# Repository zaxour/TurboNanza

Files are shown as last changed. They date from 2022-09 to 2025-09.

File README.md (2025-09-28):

# TurboNanza
[PC Engine Shuttle Installation Instructions](/images/shuttle/readme.md)

[PC Engine/Turbo Duo Installation Instructions](/images/duo/readme.md)

An internal RGB, S-Video, Composite video and Audio modification for the Turbografx 16, PCEngine and CoreGrafx. As of Revision C, support has been added for audio from the Turbo Everdrive Pro.

Design is KiCad format and all files necessary to open the design and have it fabricated are present within the archive.

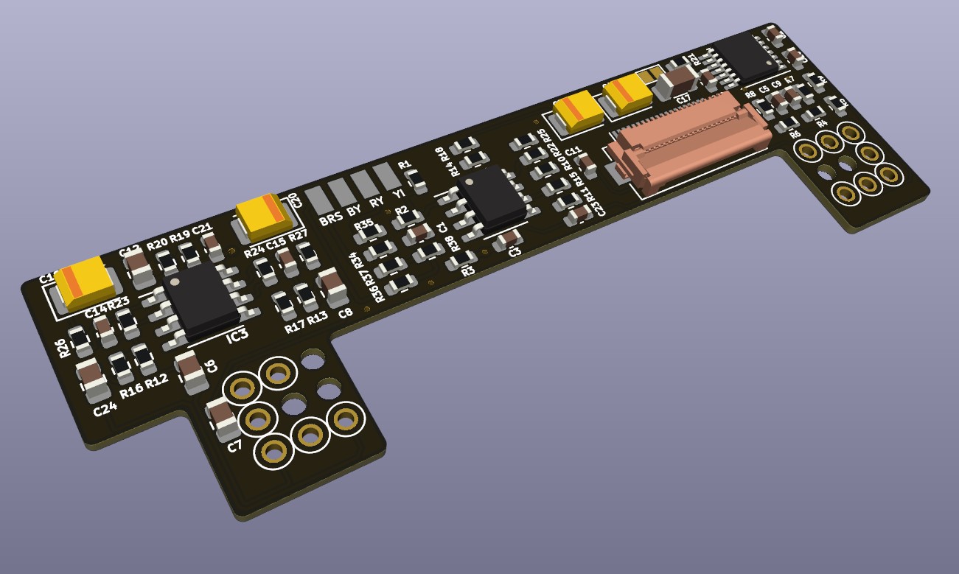
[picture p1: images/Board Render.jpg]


Installation Method (WORK IN PROGRESS!!):

PINOUT (For reference/Non-Expansion-Port Installs):
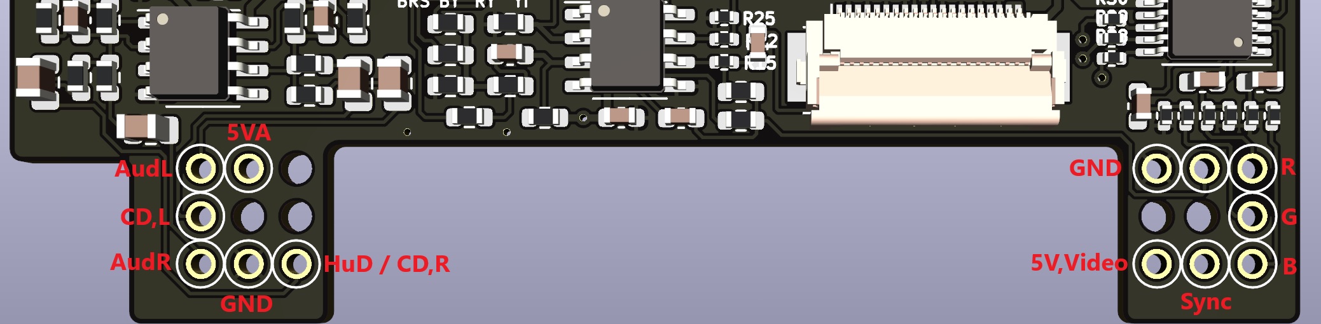
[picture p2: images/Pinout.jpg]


## Step 1 - Remove the resistors for Luma, R-Y, B-Y, and Burst
### PC Engine & CoreGrafx

Remove resistors R134, R137, R138 and R156 

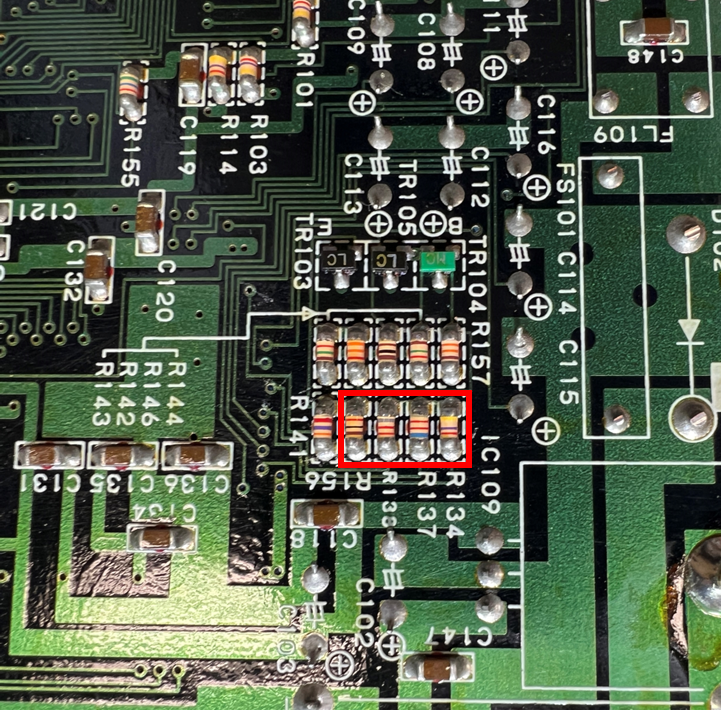
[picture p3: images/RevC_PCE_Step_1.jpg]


### TurboGrafx 16
Remove resistors R130-R132 and R134
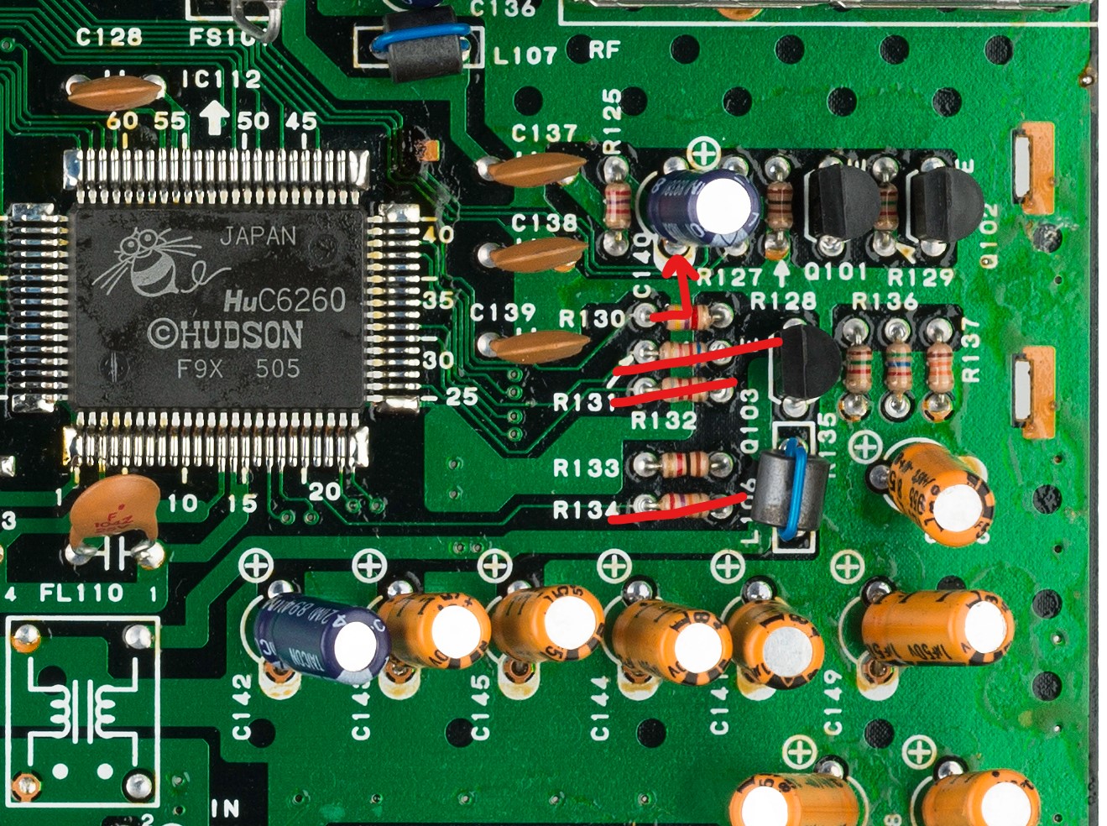
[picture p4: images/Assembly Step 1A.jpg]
Step 1


### SuperGrafx
Remove resistors R164-167
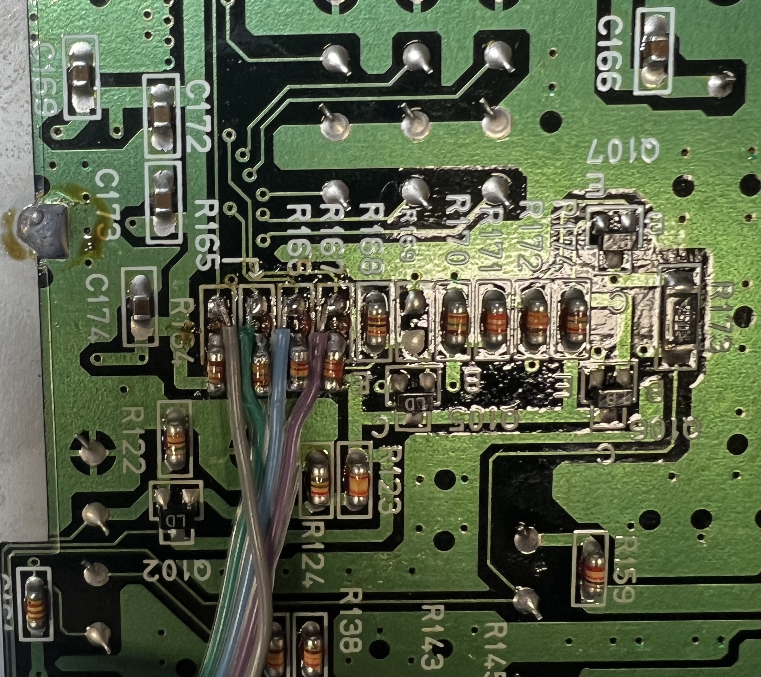
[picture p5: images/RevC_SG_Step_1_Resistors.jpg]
Step 1


## Step 2 - Disconnect CVBS pin from original circuit
### PC Engine & CoreGrafx
Remove resistor R145 (20 ohms)

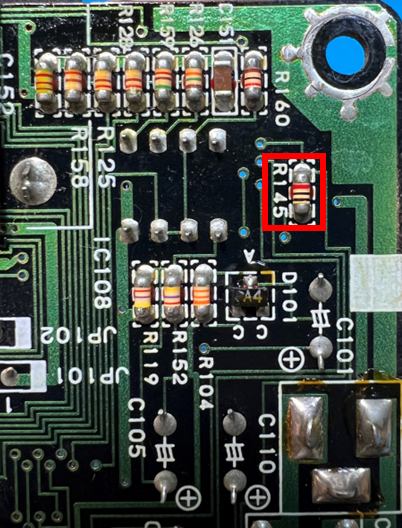
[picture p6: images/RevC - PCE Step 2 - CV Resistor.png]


### TurboGrafx 16
Remove resistor R127 (20 ohms)

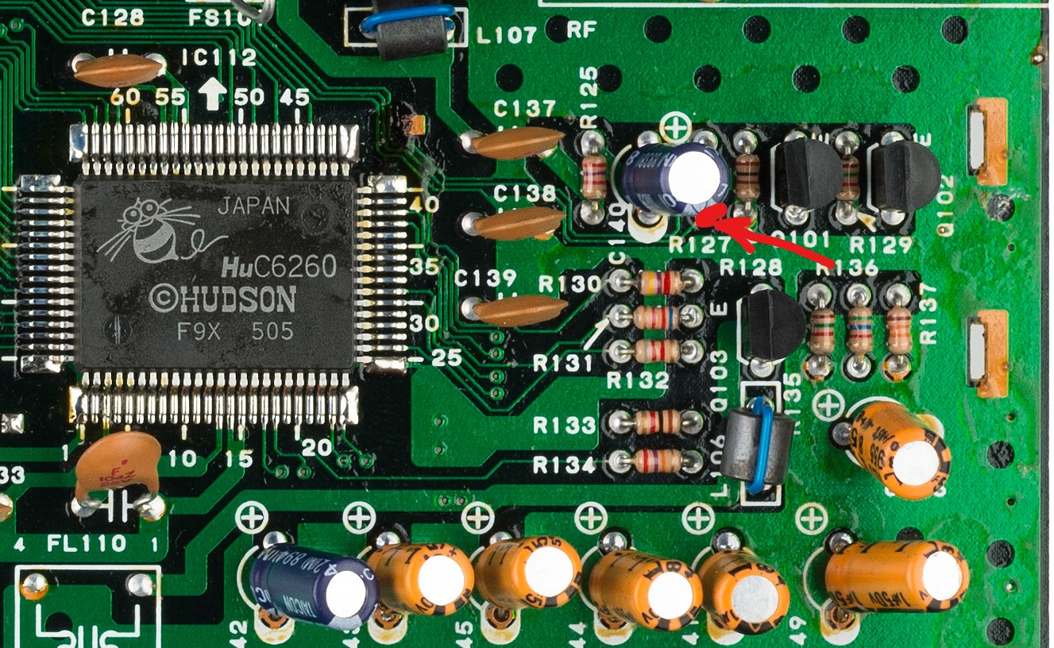
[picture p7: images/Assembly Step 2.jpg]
Step 2


### SuperGrafx
Remove resistor R147 

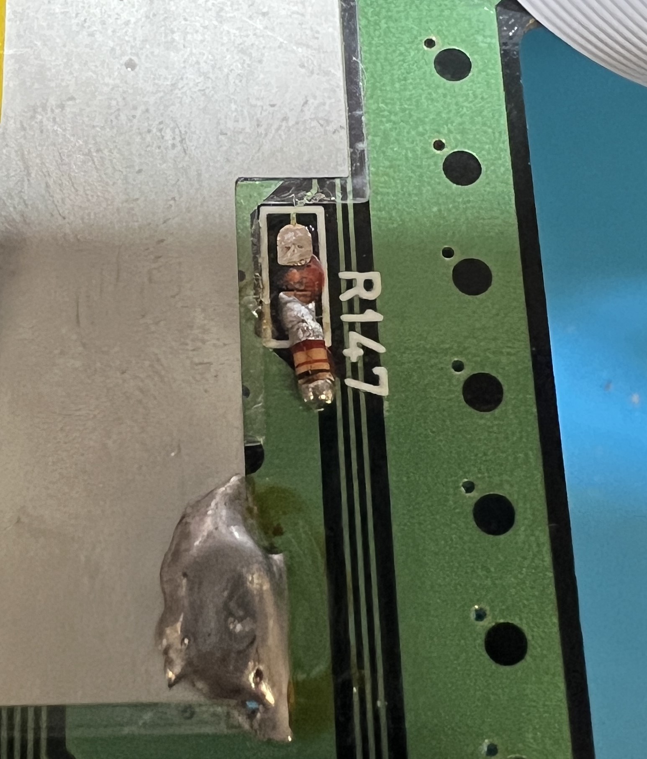
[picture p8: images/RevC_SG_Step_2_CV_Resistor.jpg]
Step 2


## Step 3 - Install TurboNanza
### PC Engine & CoreGrafx
Solder the TurboNanza over the expansion port pins as shown.
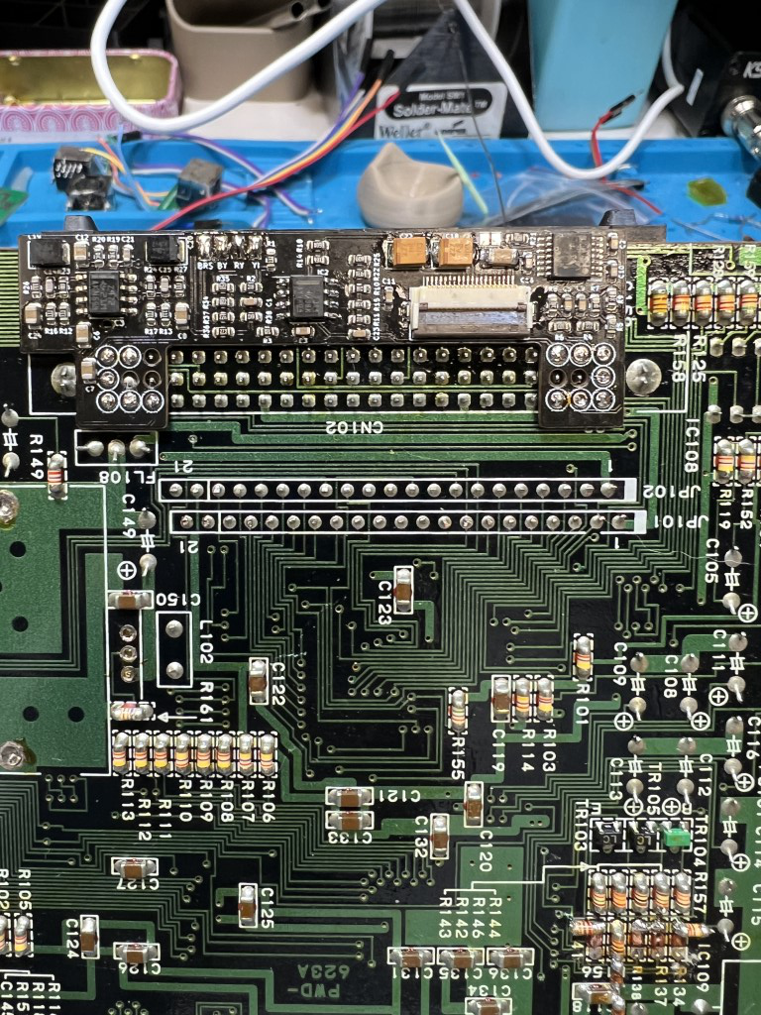
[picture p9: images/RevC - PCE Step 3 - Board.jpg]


### TurboGrafx16
Solder the TurboNanza over the expansion port pins as shown.
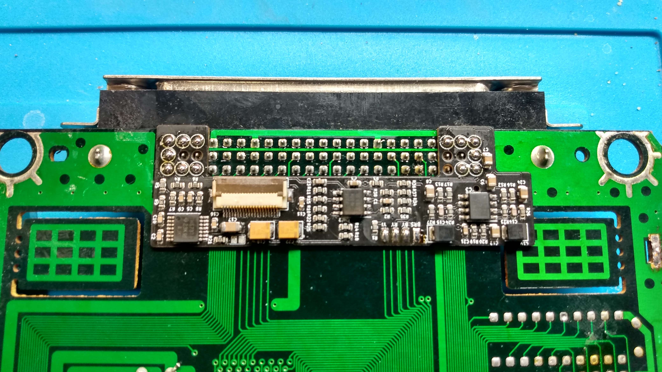
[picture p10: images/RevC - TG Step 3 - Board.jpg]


### SuperGrafx
Prepare the flex cable by tinning the pads as shown.

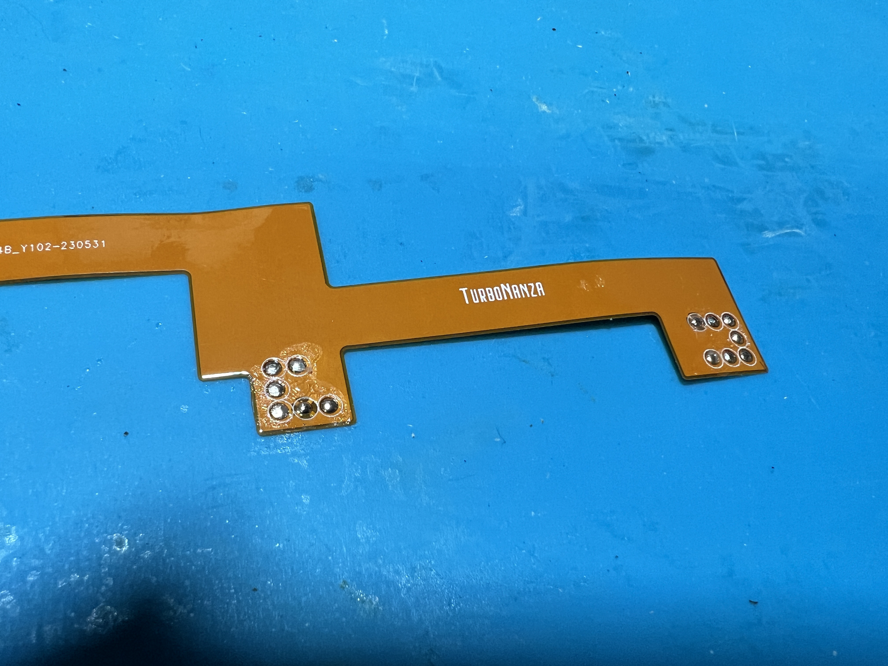
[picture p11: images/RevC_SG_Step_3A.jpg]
Step 3A


Solder the TurboNanza to the flex cable as shown. It's recommended to verify continuity. Place some kapton/polyimide tape over the exposed solder pads on the bottom of the flex cable to avoid shorting to the shielding.
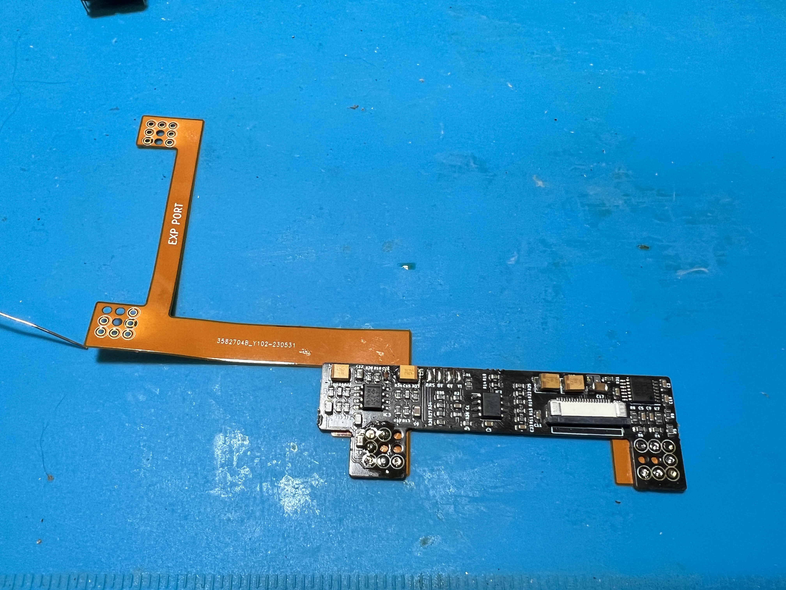
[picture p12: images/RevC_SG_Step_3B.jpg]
Step 3B


Solder the TurboNanza/Flex Cable combo over the expansion port pins as shown (ignore 4 wires at this time).
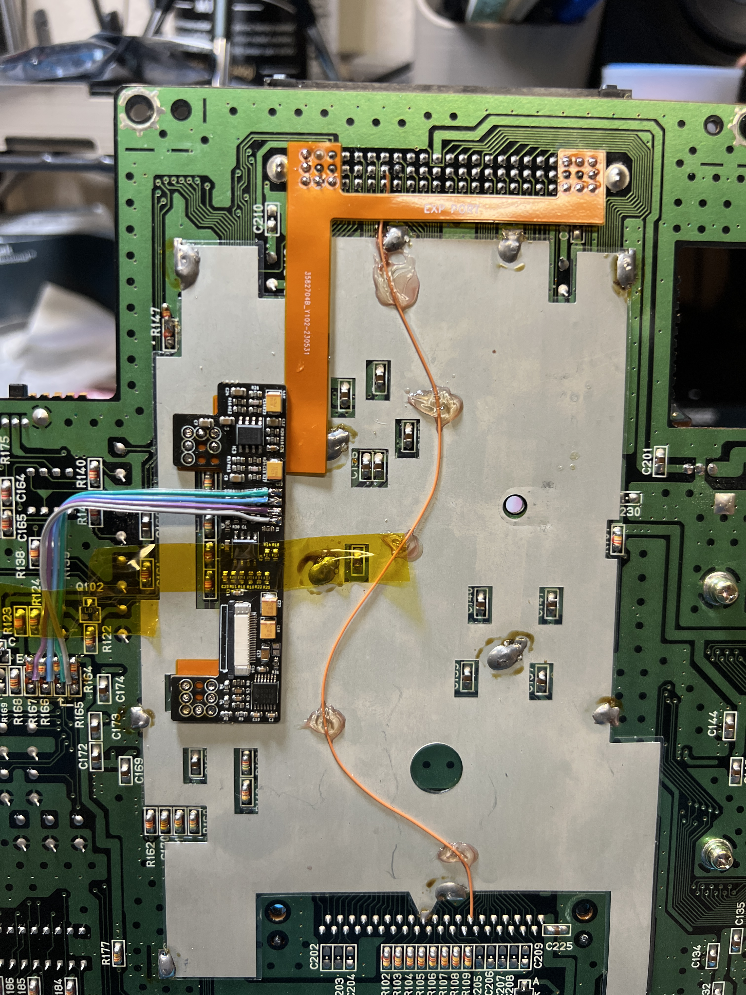
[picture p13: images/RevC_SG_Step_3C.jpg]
Step 3C


## Step 4 - Solder S-Video connections

**When soldering the Y/B-Y/R-Y/Burst wires, try to use as close to the exact same length of wire as possible to maintain proper phase shift!**

### PC Engine & CoreGrafx
Solder wires from the points shown to the pads on TurboNanza
(Do not remove R141, as previously directed. The Color Burst trace runs underneath and can easily sever. Leave R141 on and solder directly to the resistor pad)

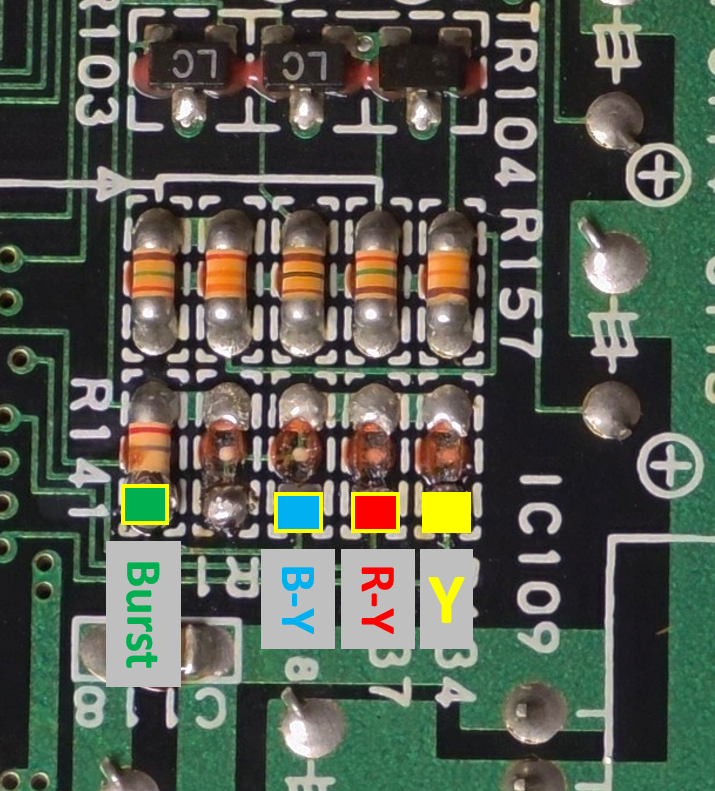
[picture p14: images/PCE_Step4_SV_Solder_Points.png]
Step 4


### TurboGrafx 16
Solder wires from the points shown to the pads on TurboNanza
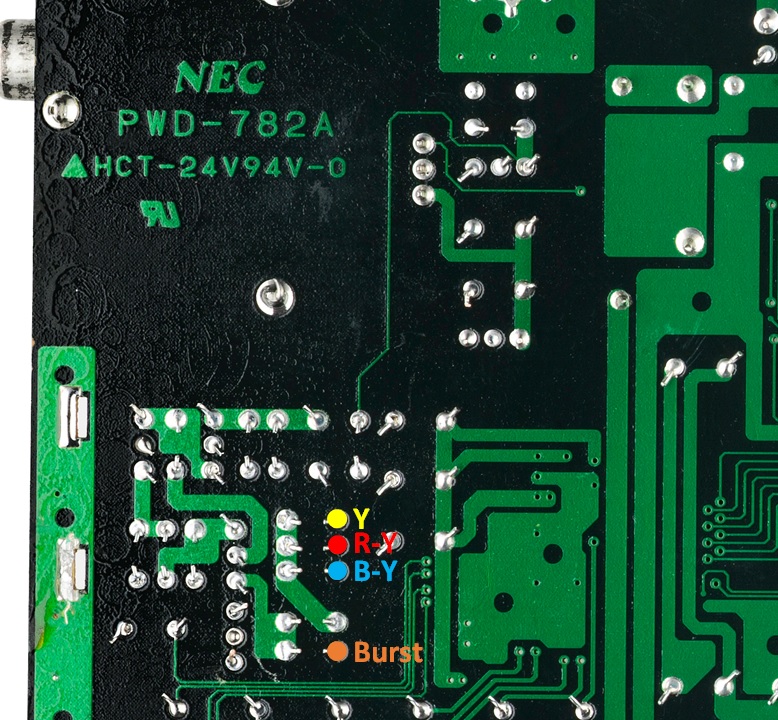
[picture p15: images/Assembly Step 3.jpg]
Step 4 Step 3


### SuperGrafx
Solder wires from the points shown to the pads on TurboNanza
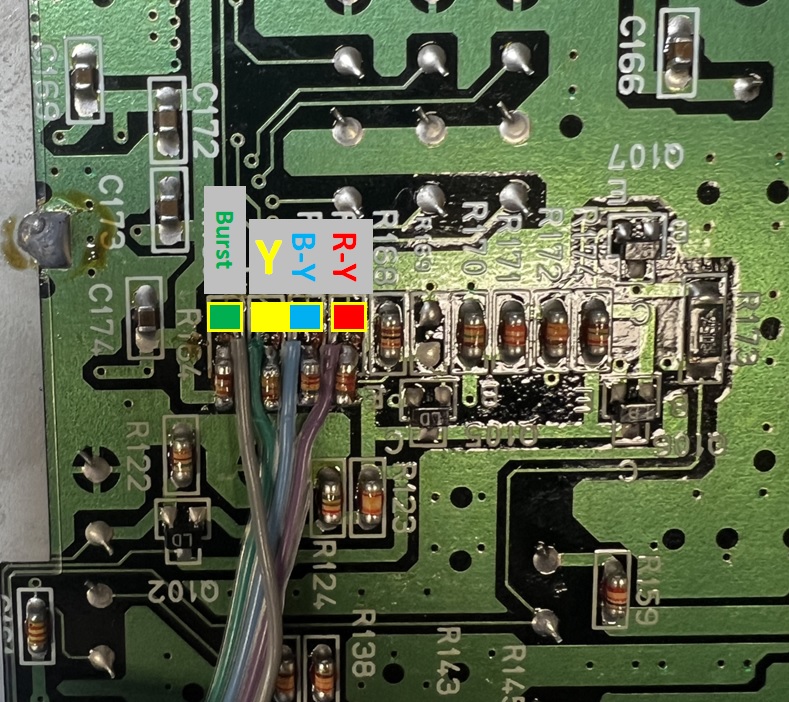
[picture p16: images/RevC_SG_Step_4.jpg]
Step 4


## Step 5 - Attach the DIN to the main board
### PC Engine
Kits sold after 8/15/2023 now include a mounting board for the PCEngine. It is recommended to secure with two size M2 or 2-56 bolts/washers to allow for easy positioning.

Position the mount and loosely secure with screws/washers. The board may also be soldered - kapton/polyimide tape is recommended to position the board.
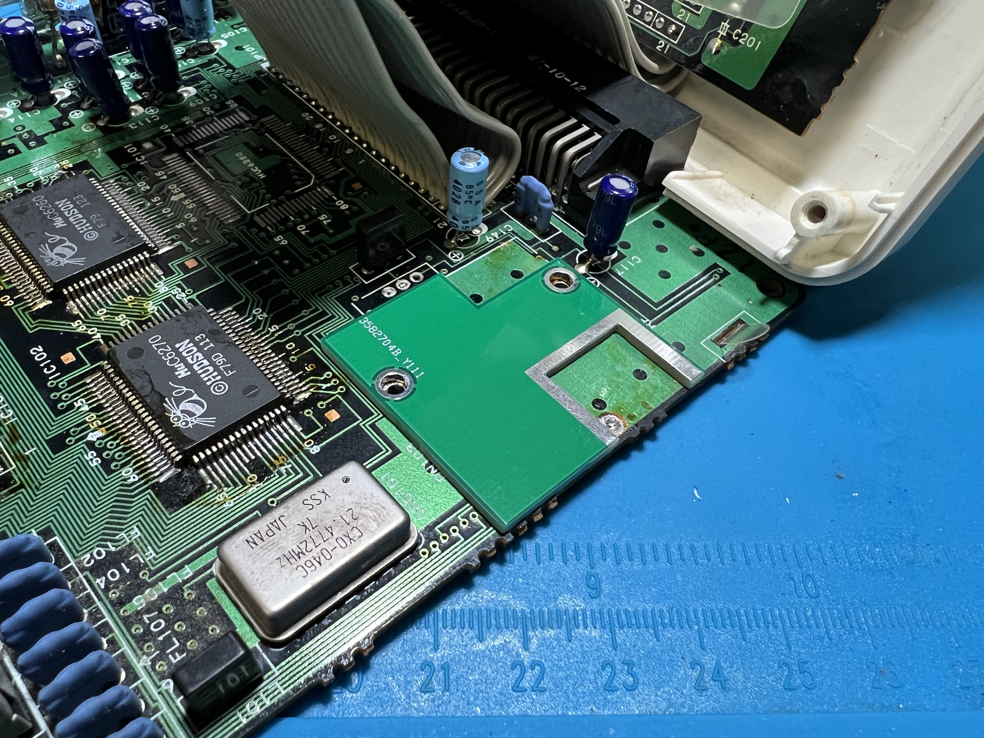
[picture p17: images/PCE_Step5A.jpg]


Place the DIN in the slot, and solder around the sides.
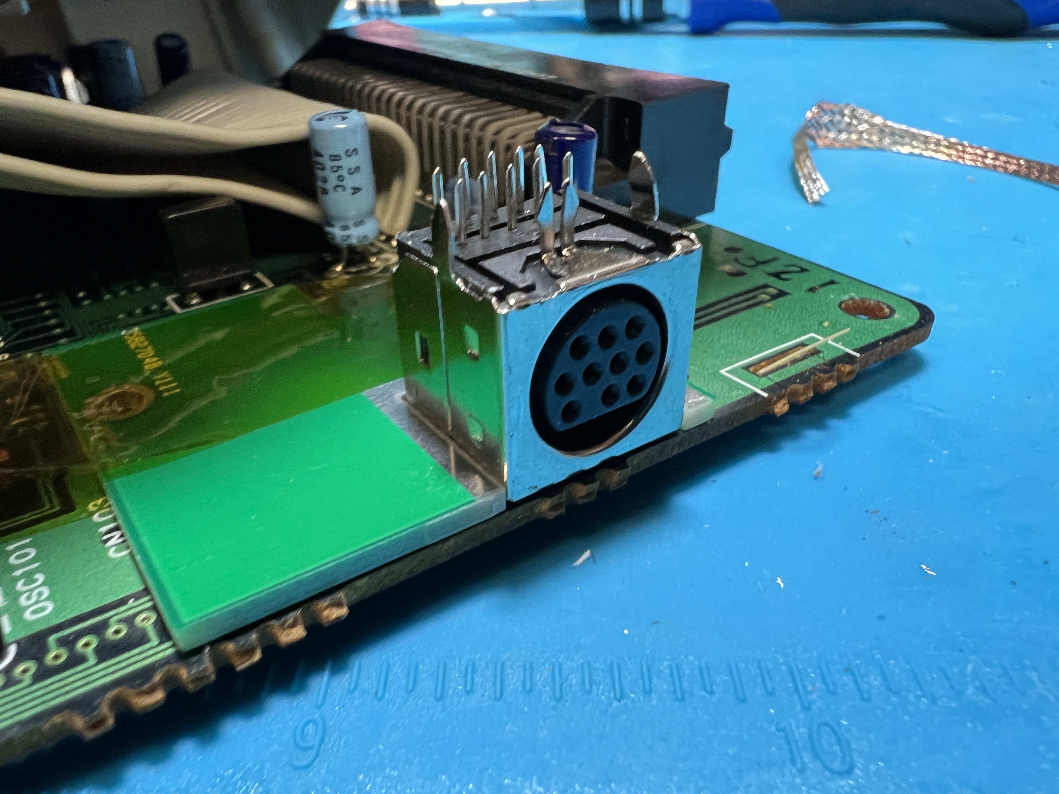
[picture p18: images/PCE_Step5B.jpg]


Solder the DIN FFC adapter to the DIN. Please make sure the "THIS SIDE TOP" text is visible before soldering, as it indicates which side is top.
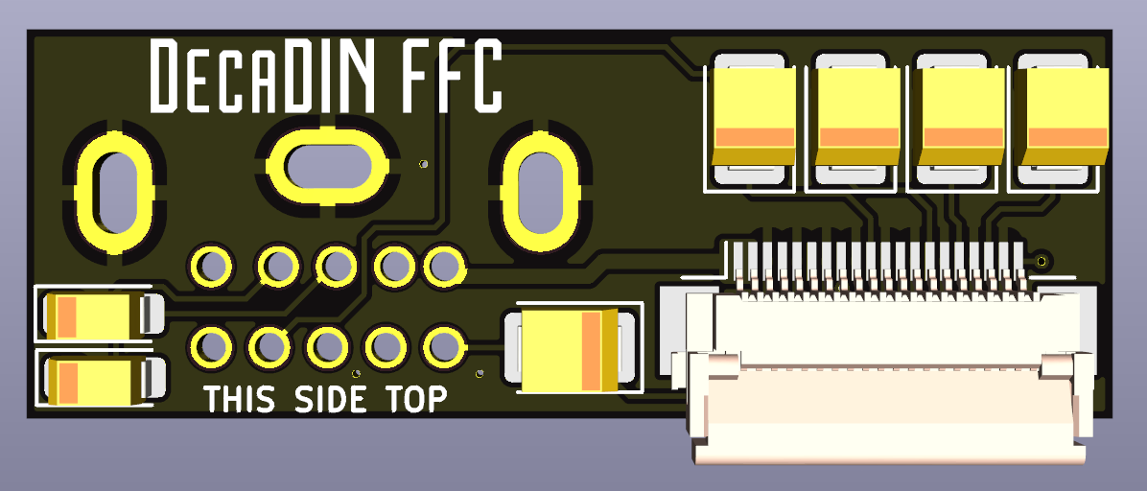
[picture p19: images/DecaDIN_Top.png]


### CoreGrafx
First, remove C162 (AC coupling capacitor for composite video - no longer necessary)
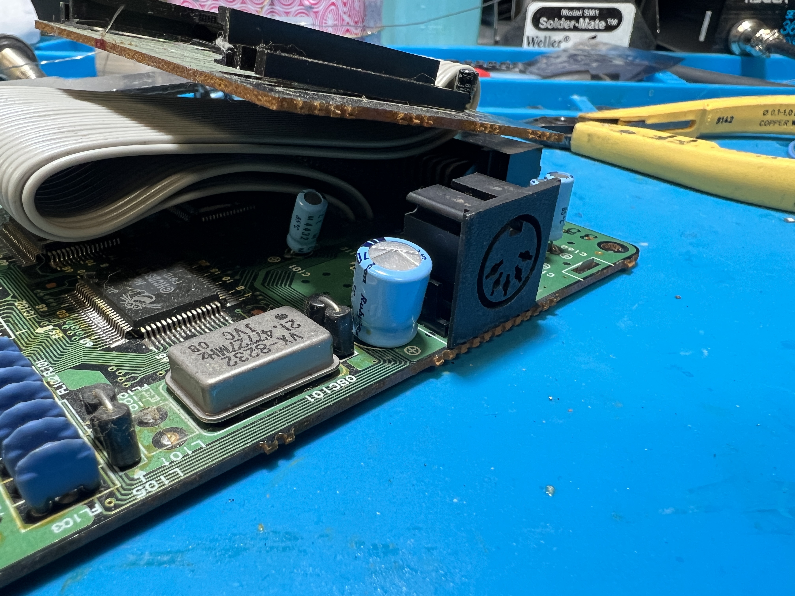
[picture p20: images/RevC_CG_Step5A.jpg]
Step 5


Scrape the solder mask off the copper on the left and right edges of the original DIN footprint as shown.
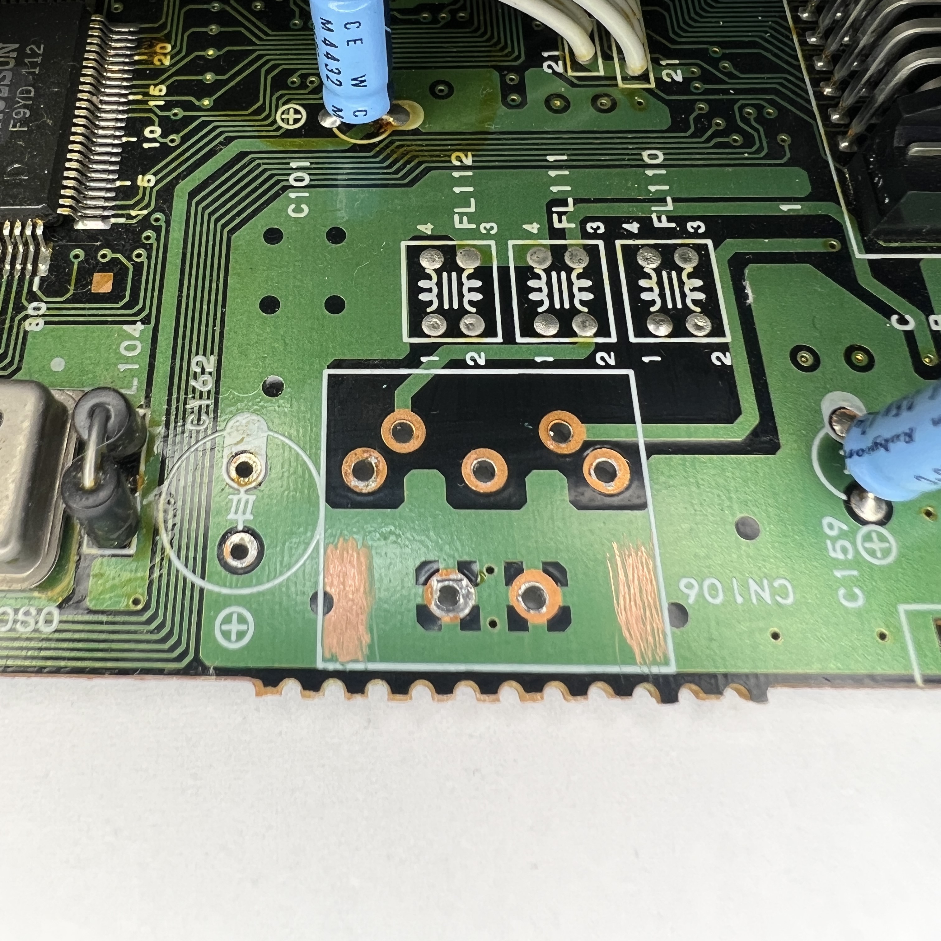
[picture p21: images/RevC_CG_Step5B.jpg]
Step 5


Solder the supplied mounting board to the mainboard.
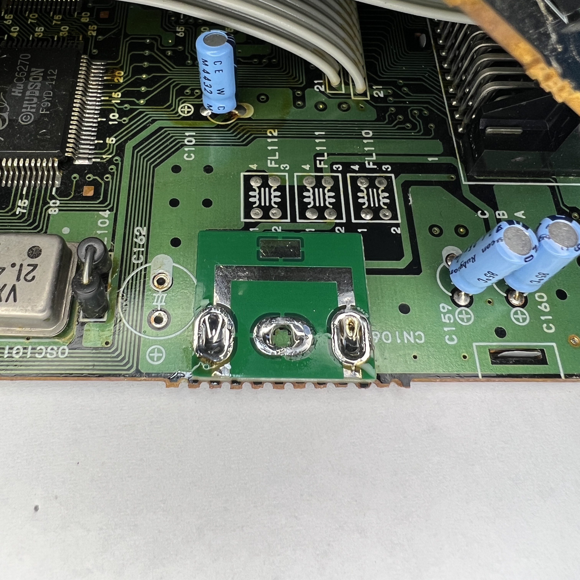
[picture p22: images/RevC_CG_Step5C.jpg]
Step 5


Solder the DIN FFC adapter to the DIN. Please make sure the "THIS SIDE TOP" text is visible before soldering, as it indicates which side is top.


### TurboGrafx16
Solder the mounting board using the plated through holes for the RF modulator. Align the DIN on the mounting board such that it aligns with the console shell opening and solder in place.

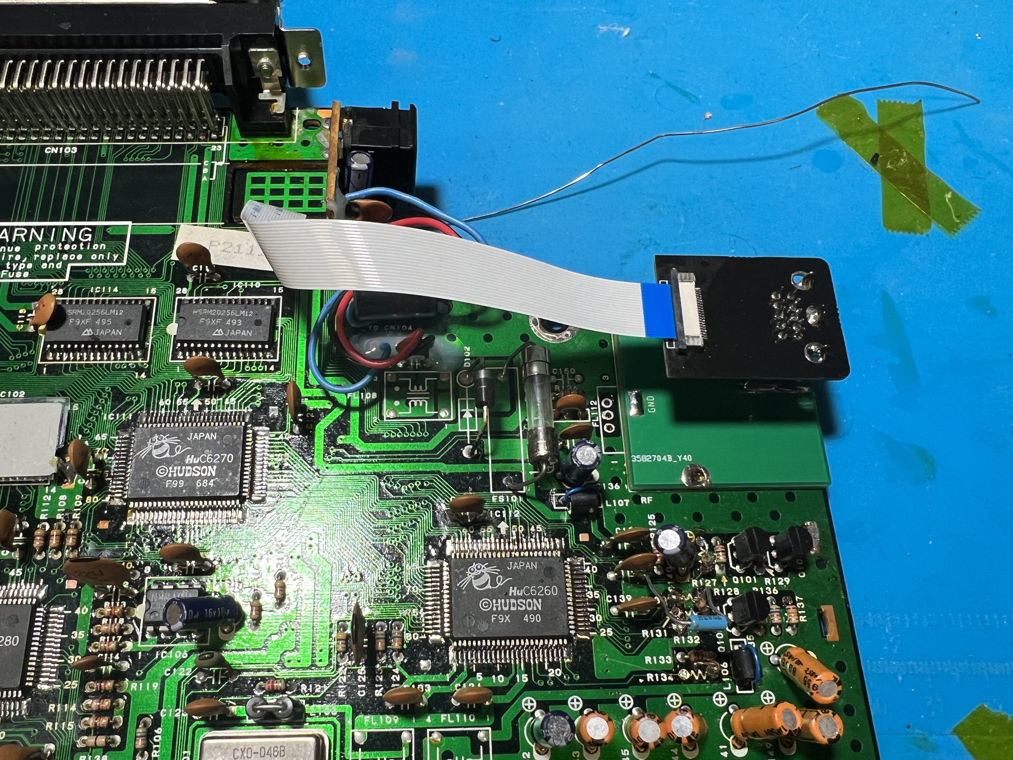
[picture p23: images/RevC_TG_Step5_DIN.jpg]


### SuperGrafx
Remove the original DIN and scrape the soldermask approximately as shown.
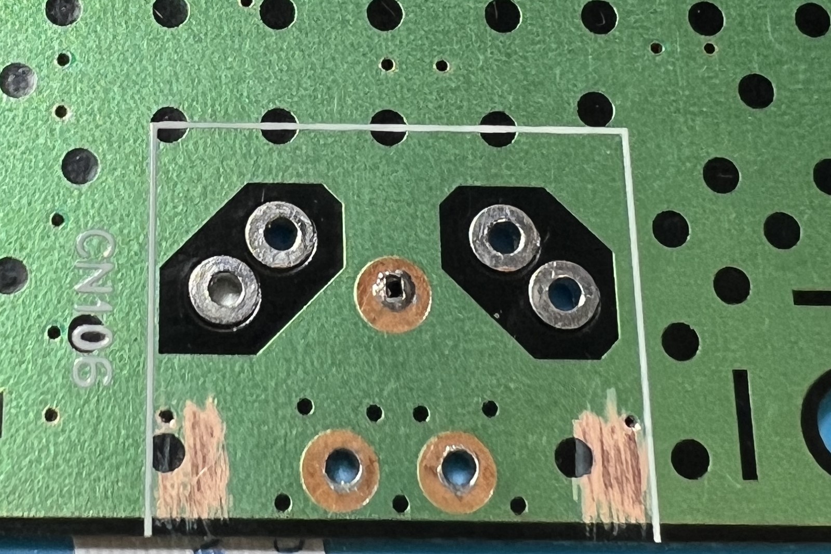
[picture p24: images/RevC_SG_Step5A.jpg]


Solder the mounting board as shown, aligning the center hole with the two ground through holes.
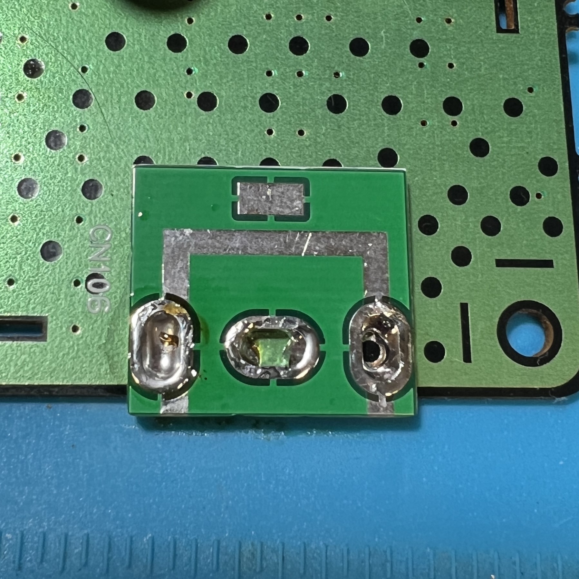
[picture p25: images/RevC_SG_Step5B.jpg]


Mount the DIN and DIN board to the mount board.
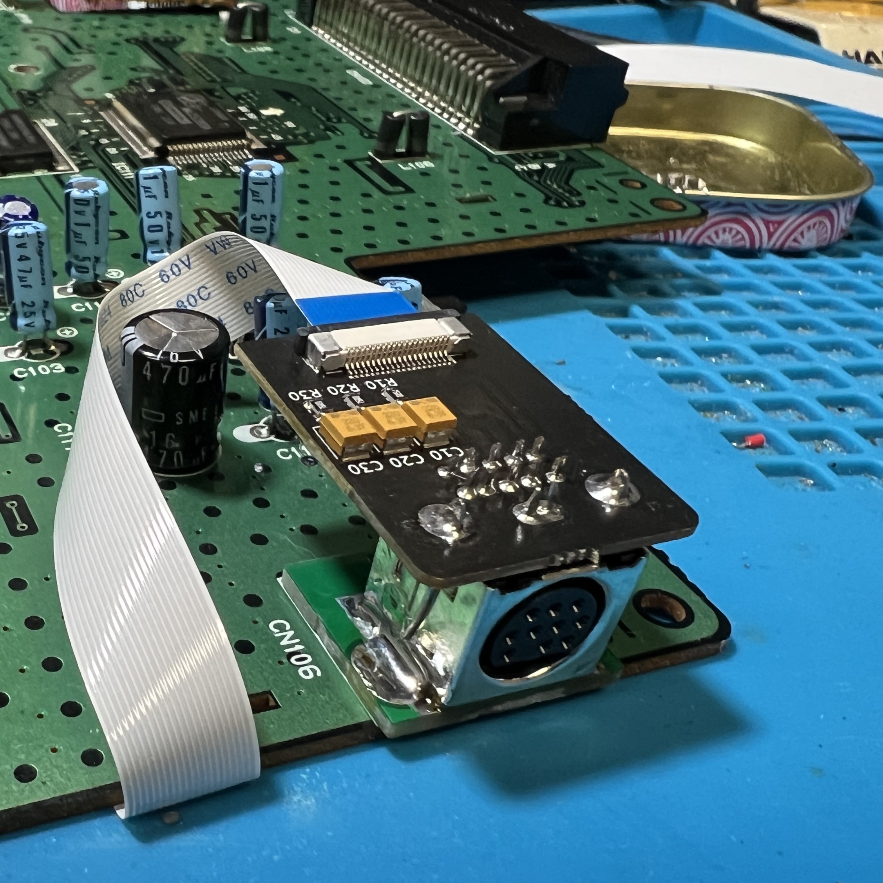
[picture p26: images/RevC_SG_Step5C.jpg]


## Step 6 - RF Shielding and Case trimming
### PC Engine
On the bottom shell of the case, trim the 2 ribs where the expansion port opening sits. Do not re-install the original shielding. If your PC Engine has shielding that has two tabs that solder close to the EXP port pins, you will need to run a wire to where the shielding originally terminated.
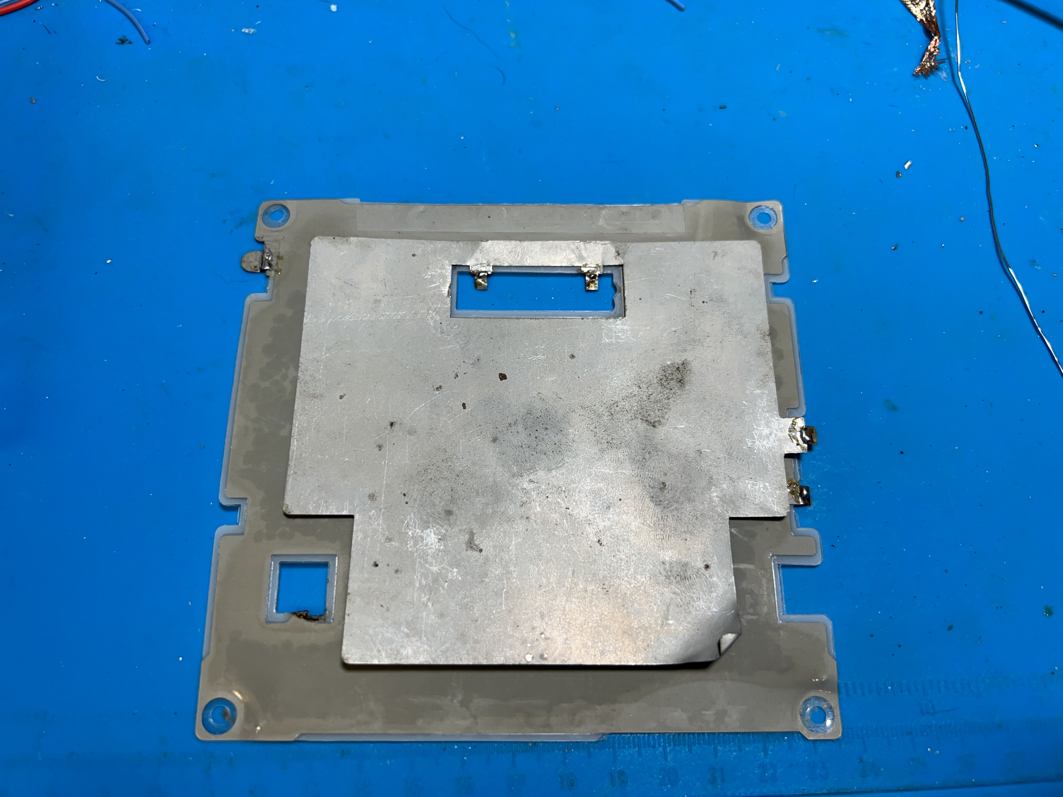
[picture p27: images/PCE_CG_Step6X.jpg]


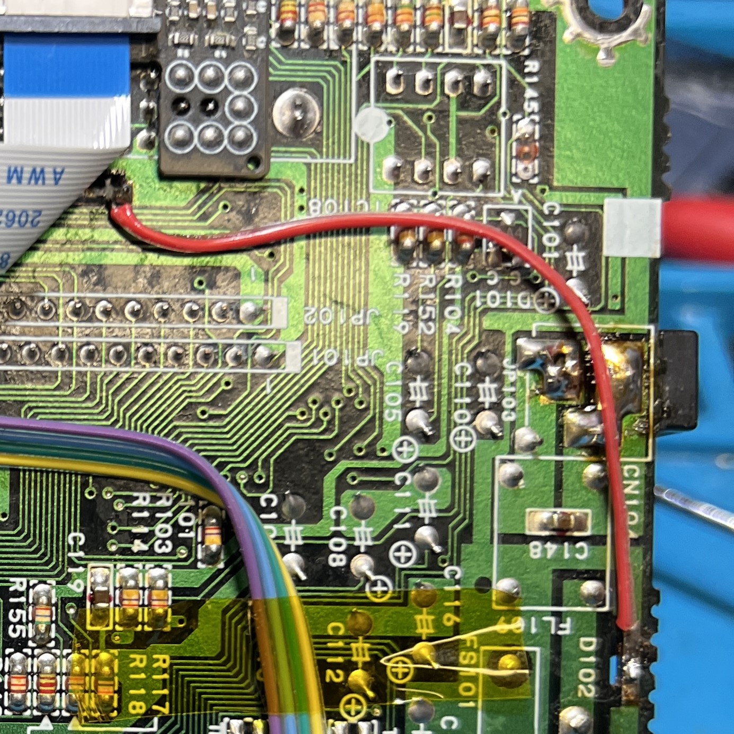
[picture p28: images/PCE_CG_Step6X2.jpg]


### CoreGrafx
Trim the RF shield such that the metal lip is not contacting the TurboNanza.

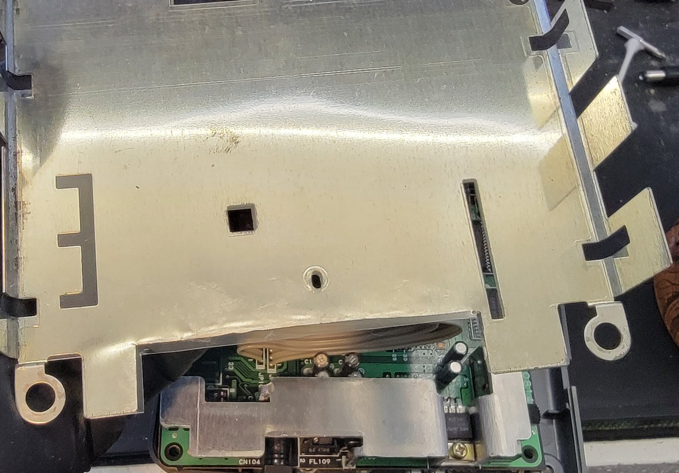
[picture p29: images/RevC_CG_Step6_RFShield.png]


Like the PC Engine, trim the 2 ribs on the bottom shell where the expansion port opening is.

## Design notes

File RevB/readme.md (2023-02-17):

# TurboNanza - Revision A/B
An internal RGB, S-Video, Composite video and Audio modification for the Turbografx 16.

Design is KiCad format and all files necessary to open the design and have it fabricated are present within the archive.



For RGB and Audio portions, simply fit the PCB over the expansion pins and solder down, then connect the output pins for RGB, Sync and Audio Left/Right to the corresponding pins of your chosen output connector.

To add S-video, First pull the left leg of R130 out of circuit as shown in the picture below, and connect the resistor to ground. Then remove resistors R131, R132 and  R134). Leave the Plated Through Holes open. Grounding R130 grounds the base for the composite mixing NPN transistor through R133.
Step 1

Next, pull the bottom leg of R127 out of circuit.
Step 2

Finally, solder your wires for Y (Luma), R-Y, B-Y, and Color Burst to the points on the bottom of the board as shown. Connect these wires to the "YI", "RY", "BY" and "BRS" pads on the TurboNanza, and solder bridge the jumper for "CV", which will send the remixed composite video to the "V" output pad on the TurboNanza.
Step 3
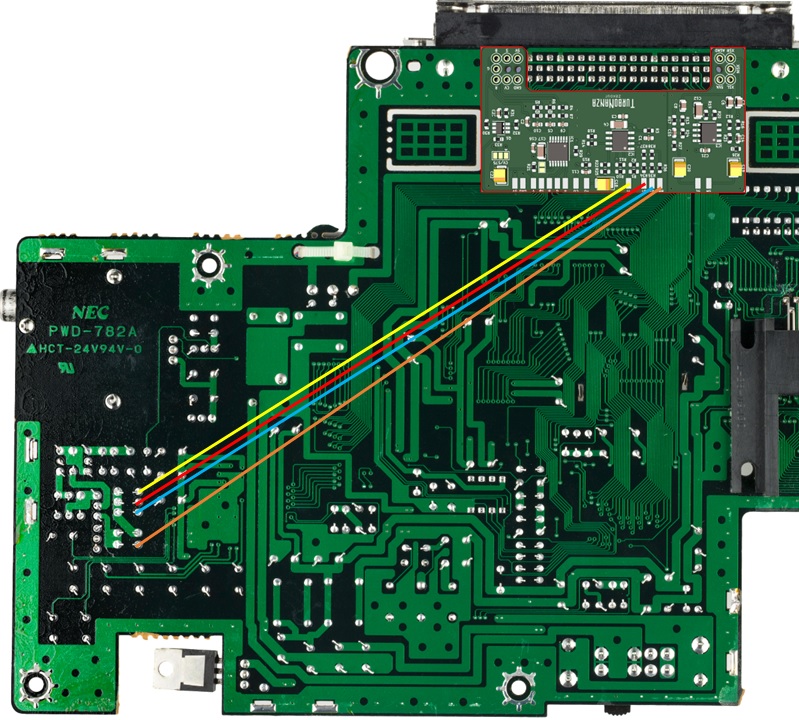
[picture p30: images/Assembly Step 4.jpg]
Step 4


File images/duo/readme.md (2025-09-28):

# Turbonanza - Duo Installation Instructions

This document covers the installation process for a PC Engine/Turbo Duo (original model). Thanks to [PowrUpGaming](https://twitter.com/PowrUpGaming) for the install photos.

The same general idea can be applied to the Duo R/RX installation, with the difference being that the HuC6260 is on the top side instead of bottom.

## Step 1 - Determine Mounting Location
Find a mounting location for the turbonanza board and secure with double-sided tape or simply with kapton tape. If using double-sided tape, wait until all of the wires are soldered before taping down.
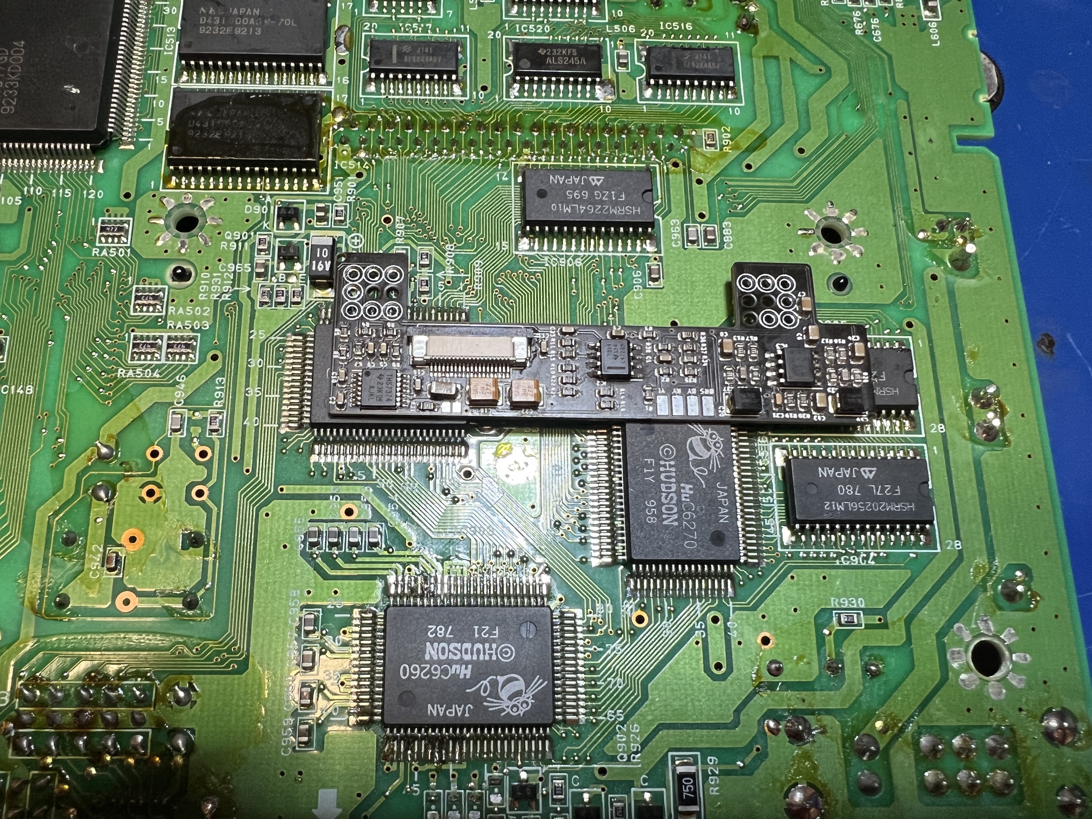
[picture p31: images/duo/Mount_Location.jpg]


## Step 2 - Solder RGB/CSYNC
Solder wires for RGB and SYNC to the HuC6260 pins as shown. The pinout is as follows:

Pin 49 - Red
Pin 47 - Green
Pin 51 - Blue
Pin 44 - Sync

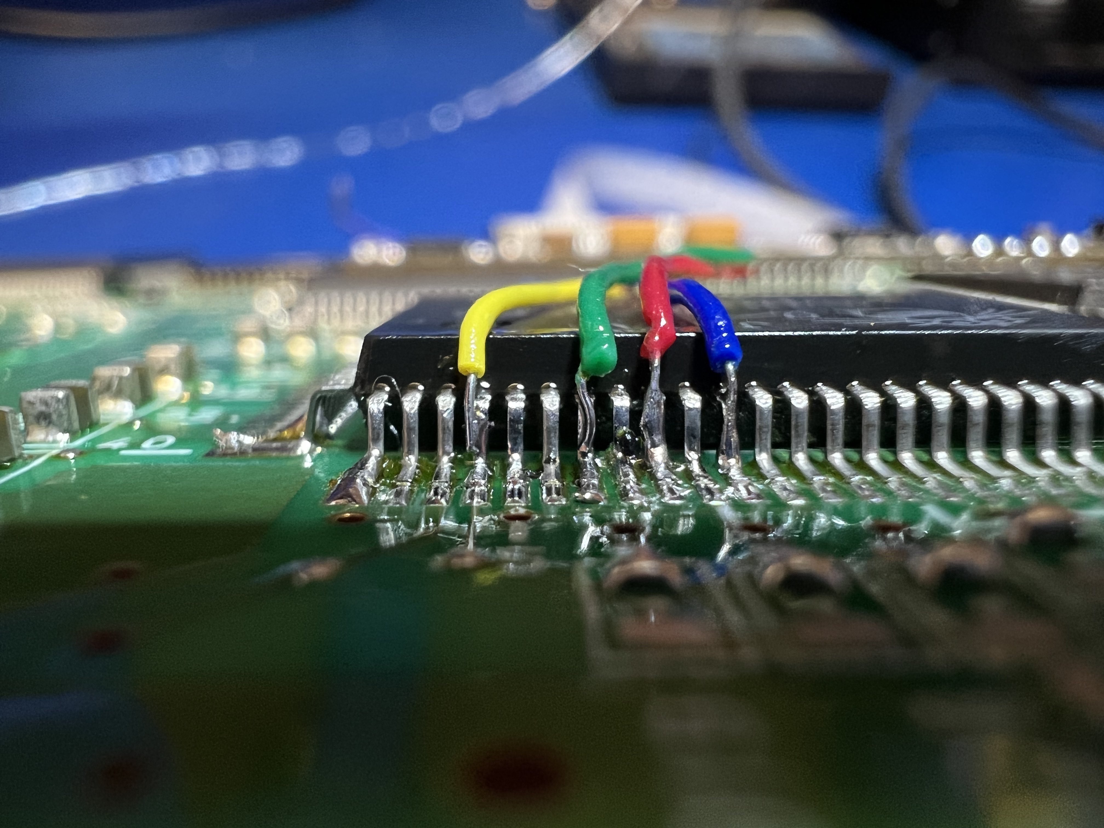
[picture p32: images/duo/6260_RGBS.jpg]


## Step 3 - Remove resistors for S-Video

Remove resistors R919-R922 and solder the 4 wires for Luma (Y), B-Y, R-Y and Burst to the pads indicated.

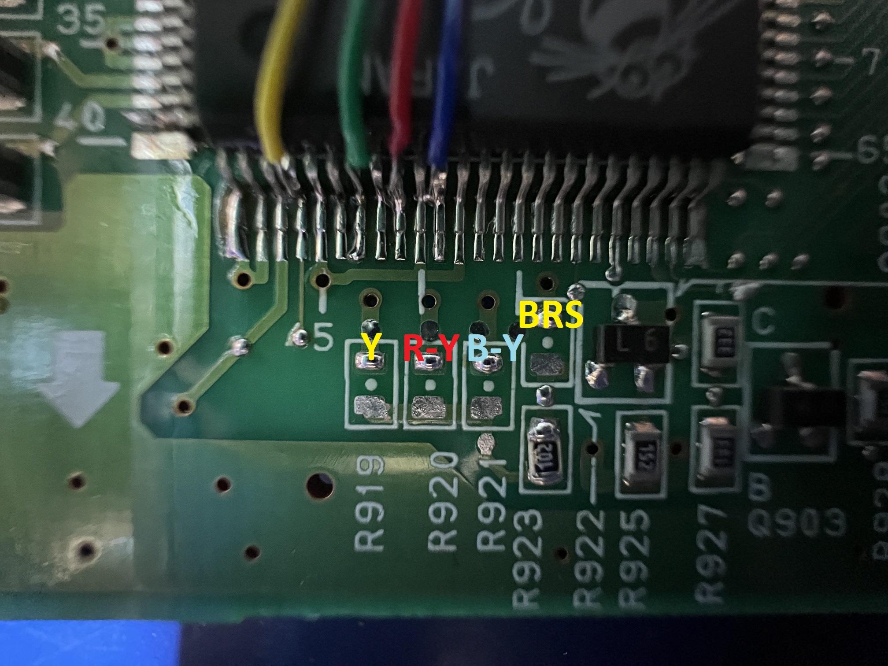
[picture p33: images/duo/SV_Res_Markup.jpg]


## Step 4 - Solder wires for 5V and GND

Locate connections for 5V and GND, preferrably across a capacitor. The following is an example - there are multiple points for 5V/GND available.

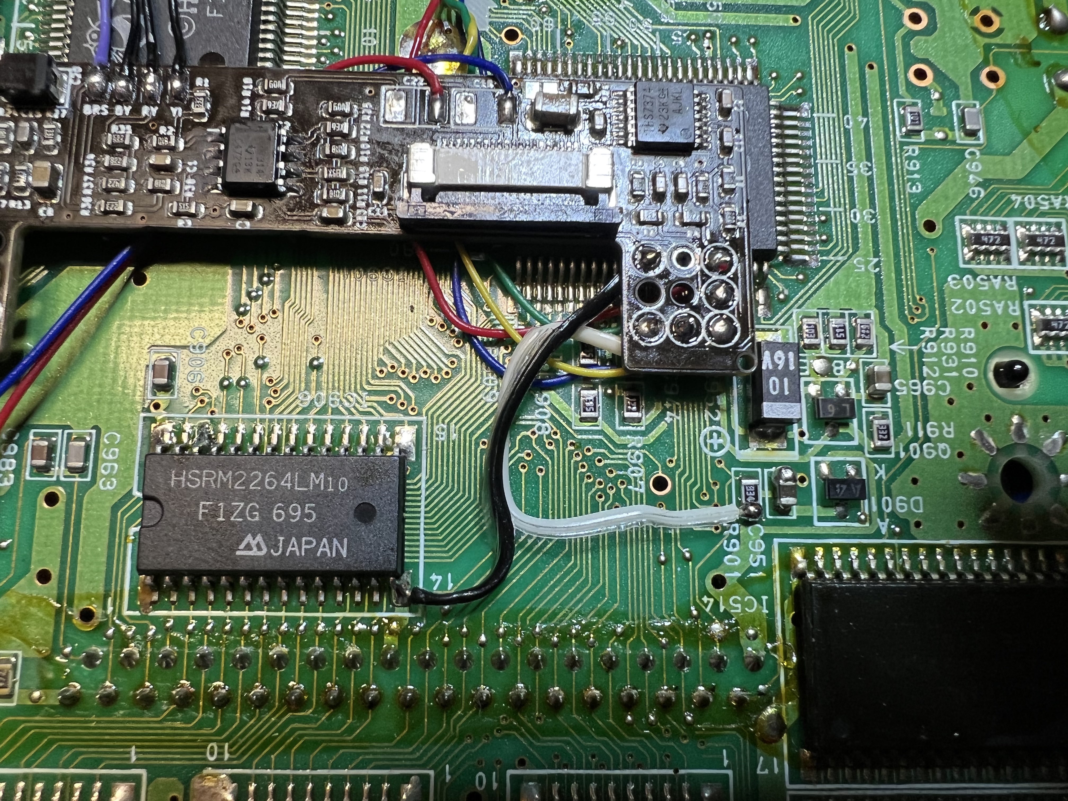
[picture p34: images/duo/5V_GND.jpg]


## Step 5 - Solder all wires to to the Turbonanza

All connections are labeled on the bottom of the board, but this image may also be used as reference.

At this time, the following connections should be made to the turbonanza:
5V, GND, R, G, B, Sync, Y, R-Y, B-Y, Burst

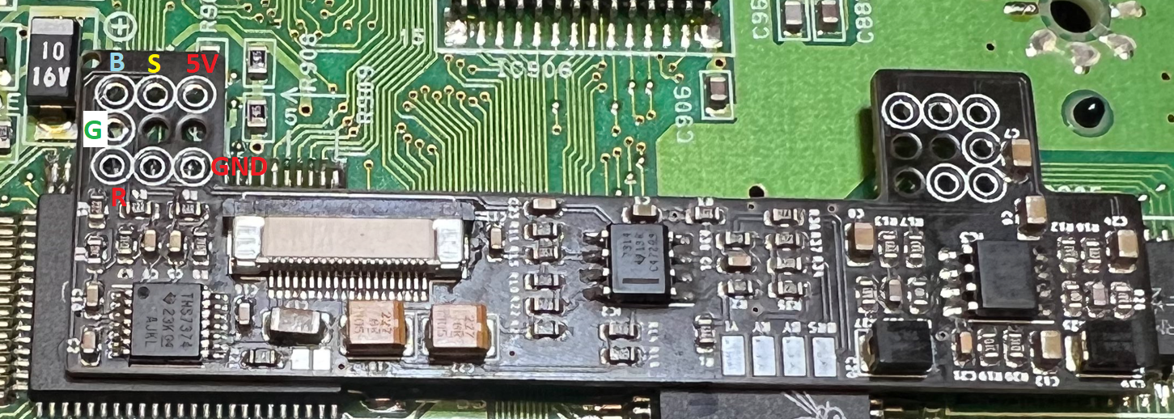
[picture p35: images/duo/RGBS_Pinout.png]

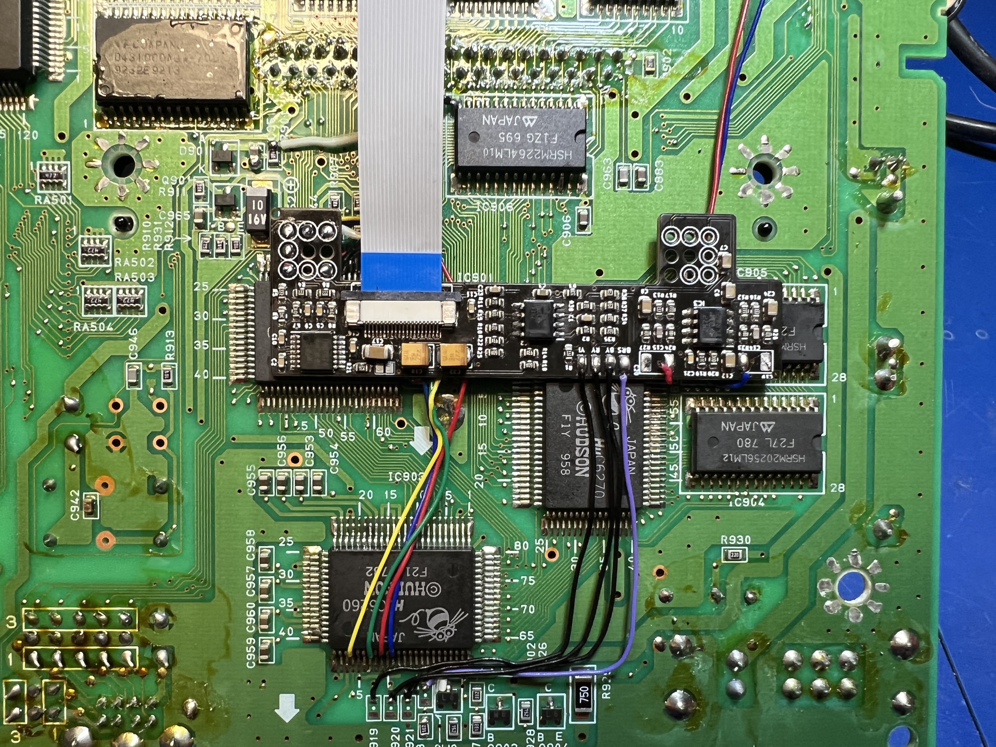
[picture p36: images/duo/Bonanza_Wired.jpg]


## Step 6 - Remove original 5 Pin DIN, install 10 Pin DIN

See CoreGrafx for DIN and mounting board installation.

## Step 7 - Audio

Tap the Duo's audio output circuit - the signals can be directly obtained from the original DIN pins as shown below. 

The blue wire is Left audio, while the red wire is for Right audio.

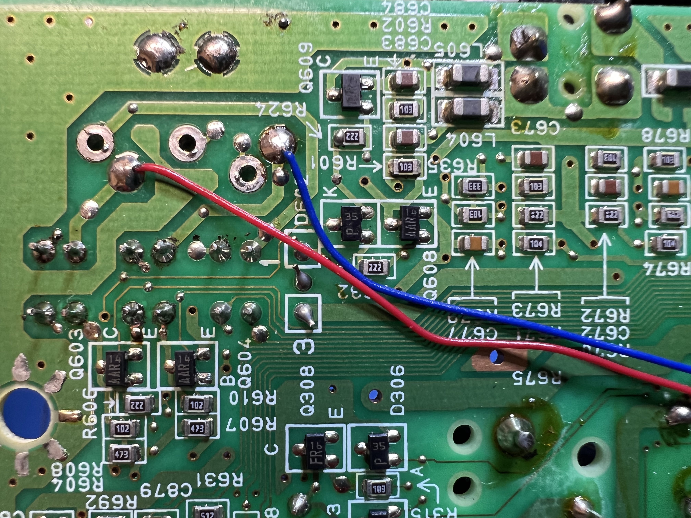
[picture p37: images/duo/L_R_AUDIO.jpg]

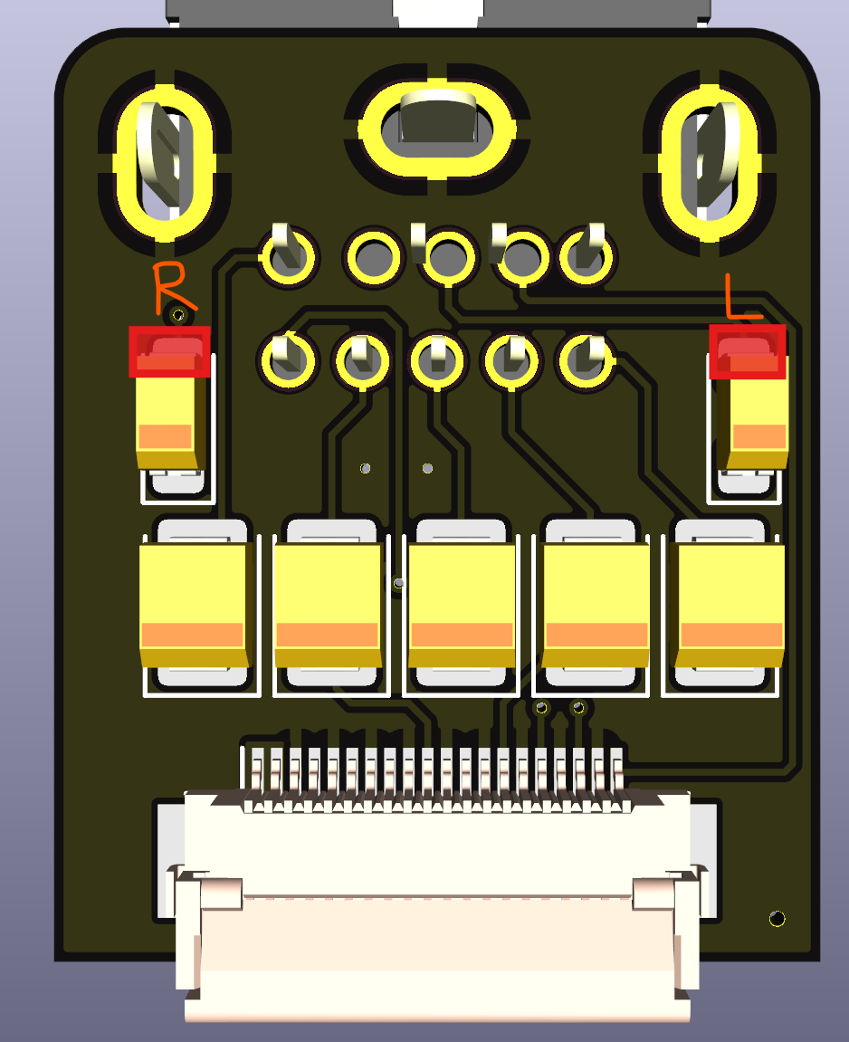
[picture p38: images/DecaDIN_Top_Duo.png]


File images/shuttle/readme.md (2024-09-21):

# Shuttle Installation

NOTICE - this will require some interior trimming of the case. Nothing major, but be forewarned.

## Step 1 - Remove Video Resistors

On the bottom side of the board, remove resistors R134, R137, R138, R156 and R141, as shown in the red boxes.

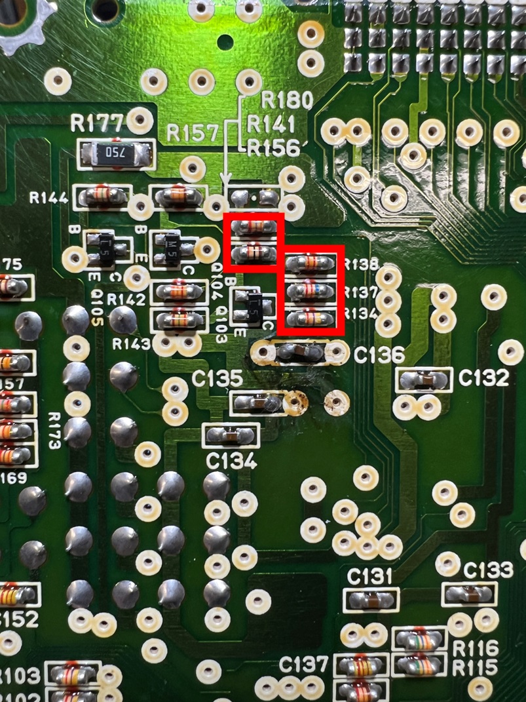
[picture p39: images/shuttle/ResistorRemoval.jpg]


## Step 2 - Optional HuFlex Install

Tin both sides of the HuFlex pads that will solder to the HuC6260. Also flux/reflow the solder around the HuC6260 to facilitate installation. Finally, carefully install the flex as shown.

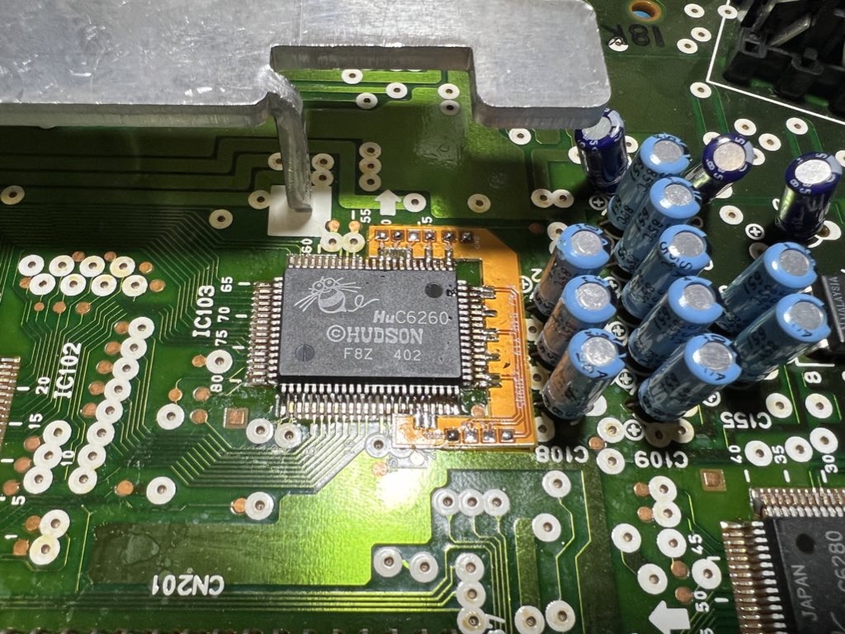
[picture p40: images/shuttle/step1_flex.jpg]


## Step 3 - Remove Audio/Video Capacitors

Remove the capacitors in the red boxes.

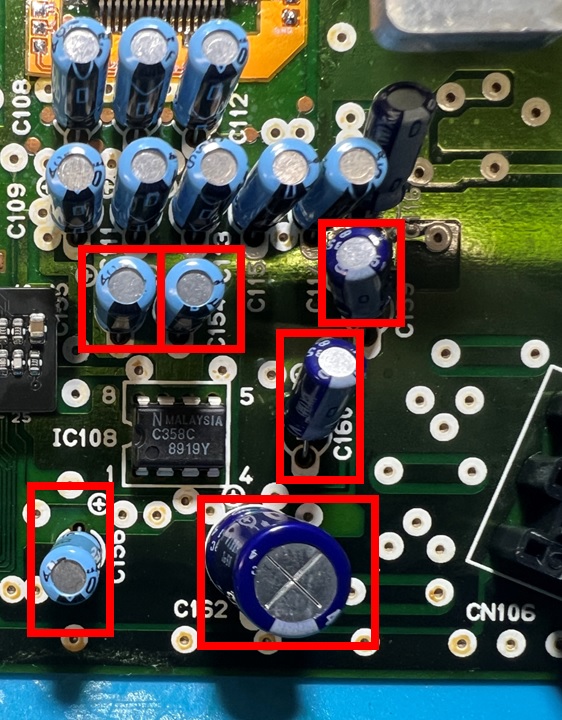
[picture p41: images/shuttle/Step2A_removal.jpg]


## Step 4 - Remove Original DIN, install mounting board

Remove the stock 5-pin DIN and install the mounting board (see CoreGrafx for more detail). 

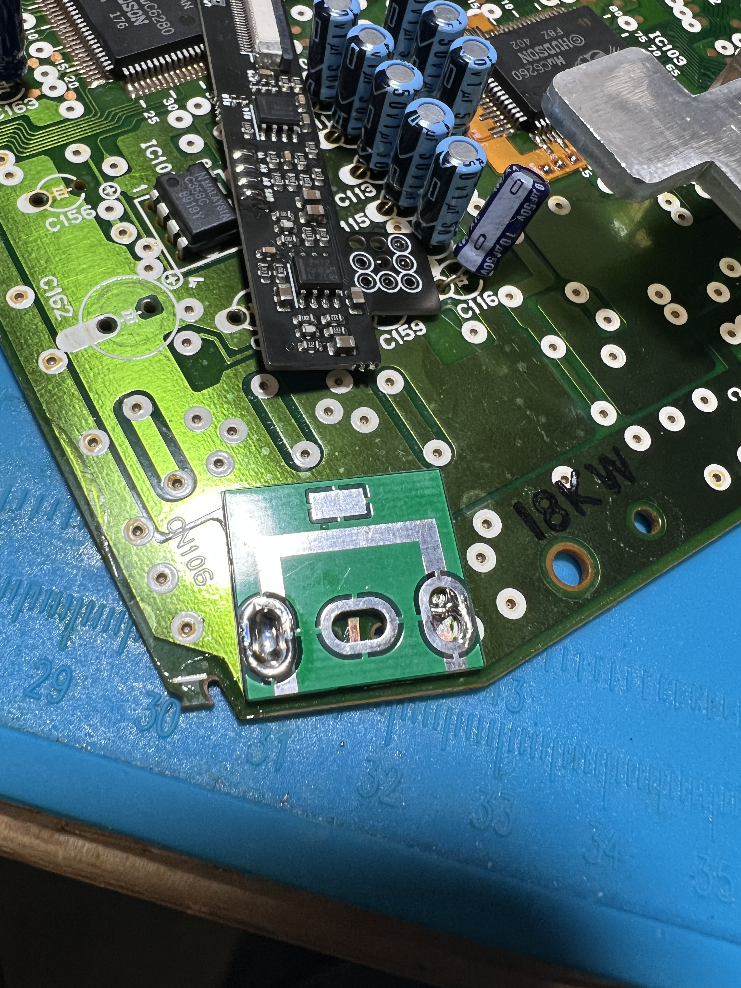
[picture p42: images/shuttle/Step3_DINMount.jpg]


## Step 5 - Trim interior ribbing

Cut the 4 small tabs off of the top shell flush with the rest of the surrounding features.

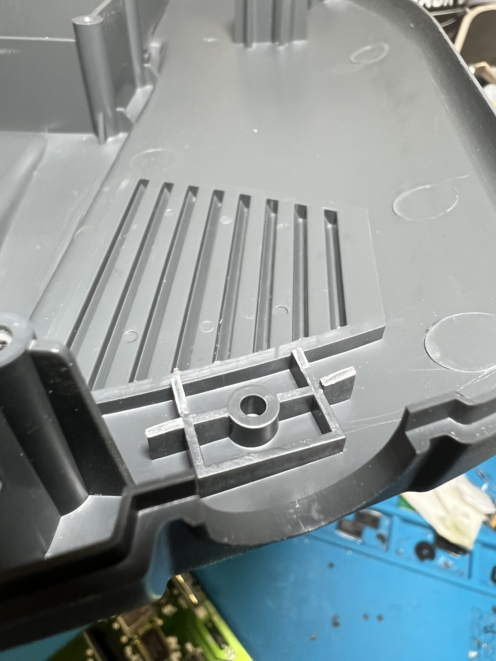
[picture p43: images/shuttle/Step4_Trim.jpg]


## Step 6 - Solder DIN

Solder the 10 Pin DIN to the DIN Mount board.

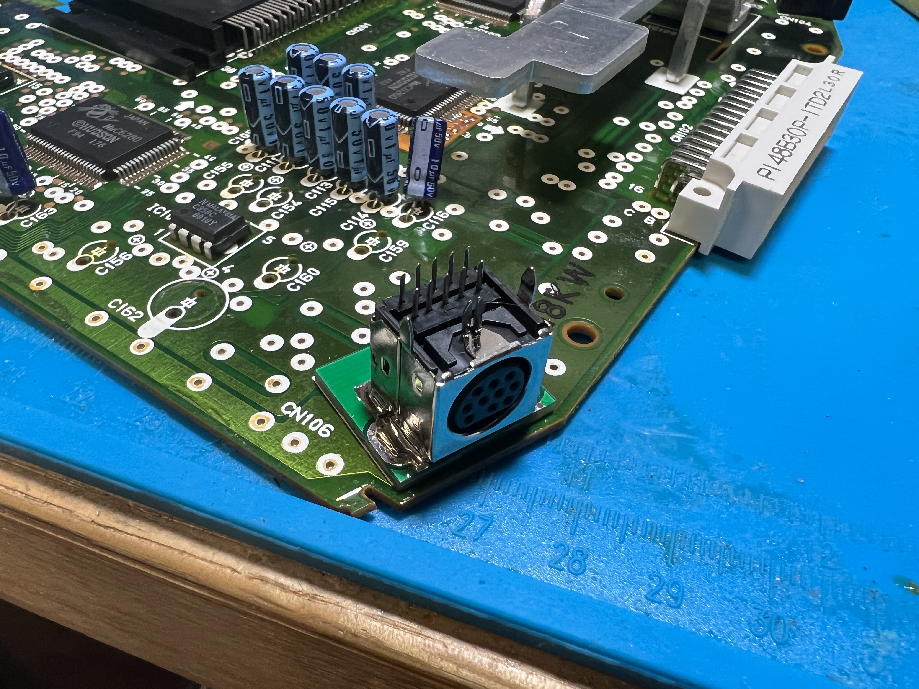
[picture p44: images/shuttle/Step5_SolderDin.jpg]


## Step 7 - Solder Video Connections

Solder the video connections from the HuFlex to the Turbonanza board. Refer to the pinout below. Y / B-Y / R-Y / Burst are marked on the Turbonanza itself.

If not using the HuFlex, the HuC6260 pins are as follows:

Red - P49
Blue - P51
Green - P47
Sync - P44

5V/GND - Most convenient wiring location

Y - P40
R-Y - P33
B-Y - P26
Burst - P20


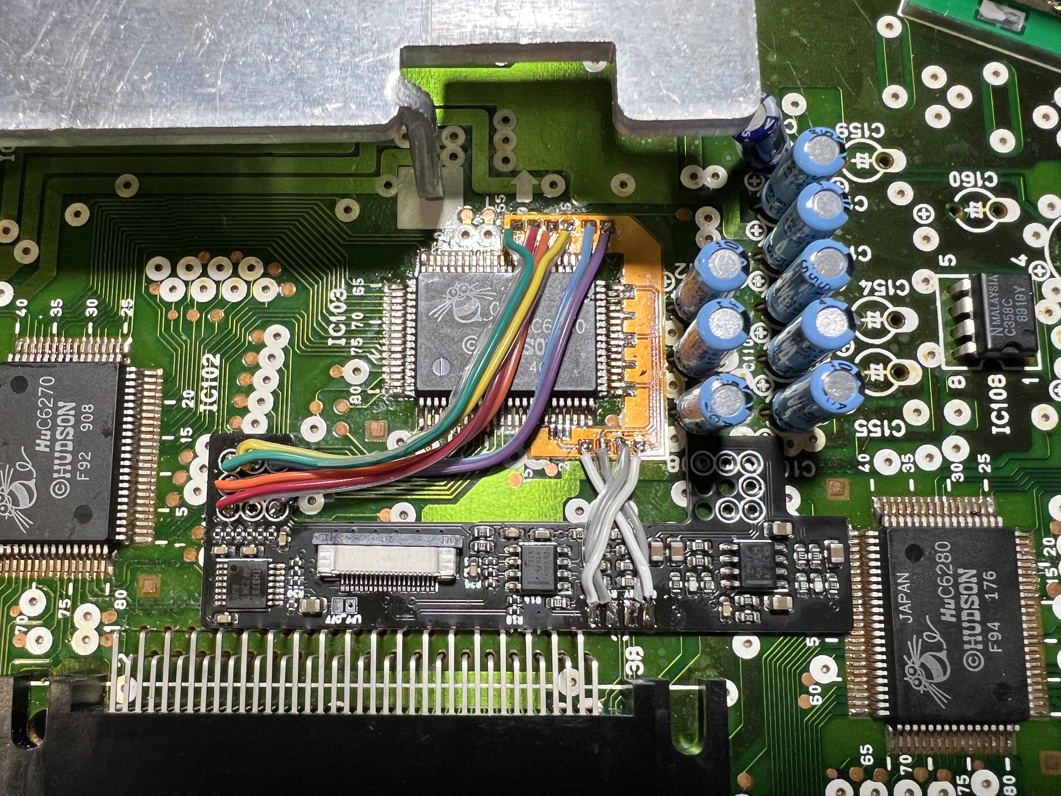
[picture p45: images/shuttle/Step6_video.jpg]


## Step 8 - Solder HuD / CD Audio Left connection

Solder a wire to Pin 1 of the cartridge slot, then connect to the HuD/CDR pin on the Turbonanza.
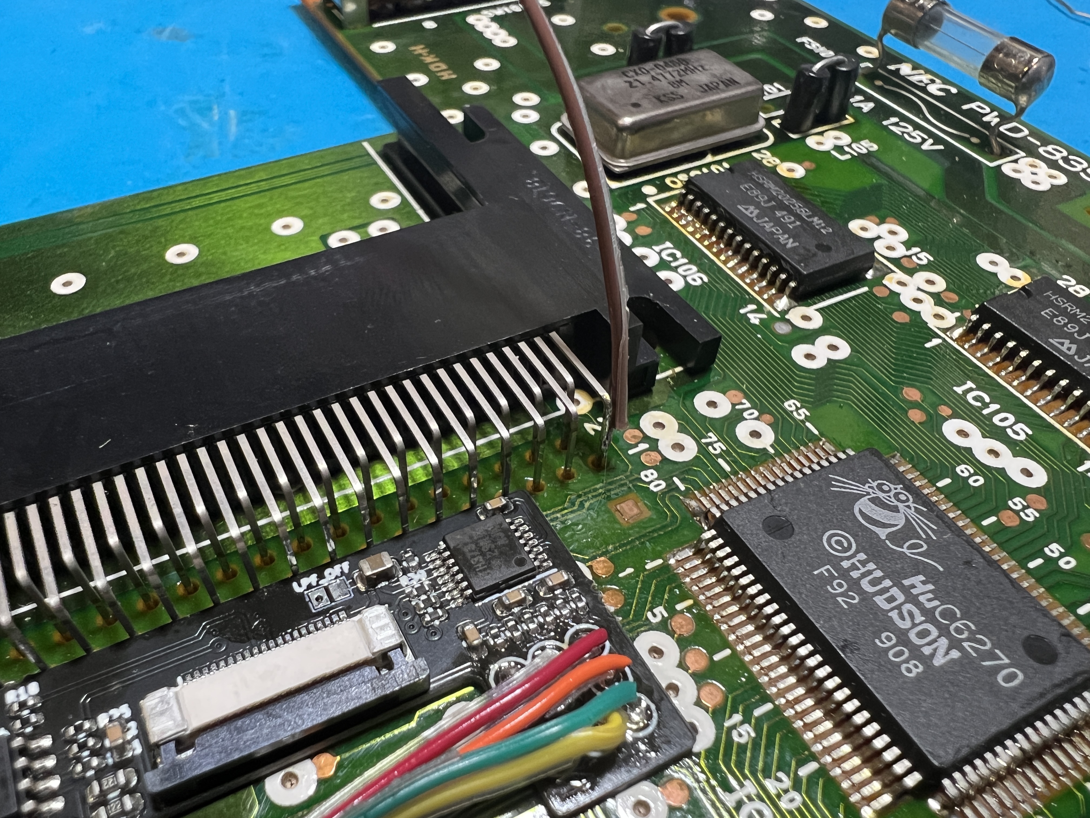
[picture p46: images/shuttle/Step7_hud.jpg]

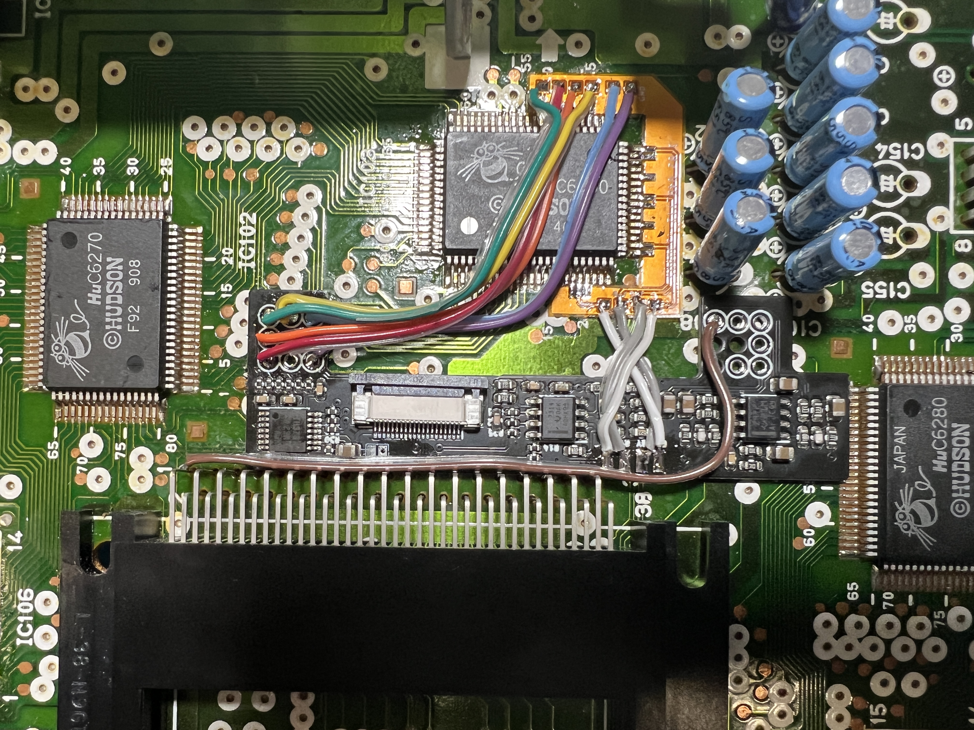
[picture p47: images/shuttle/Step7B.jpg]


## Step 9 - Solder Remaining Audio Connections

Solder the Audio Left/Right, CD Left and 5VA connections. See the following image for signal locations.
*NOTE* Pin 2 on the HuCard slot can also be used for "CD Left"

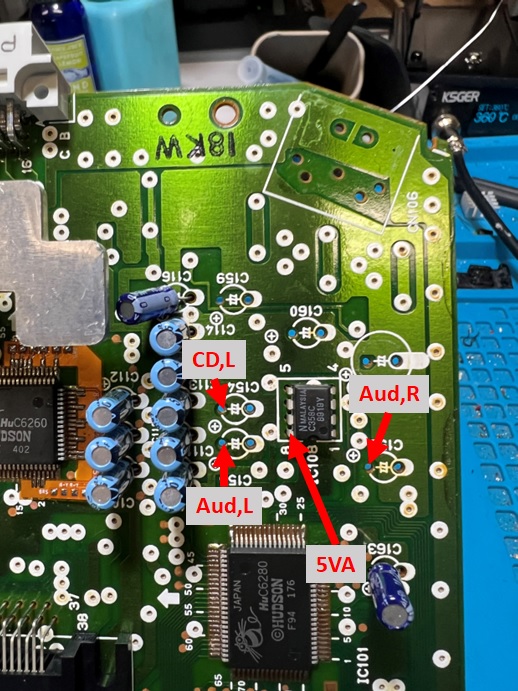
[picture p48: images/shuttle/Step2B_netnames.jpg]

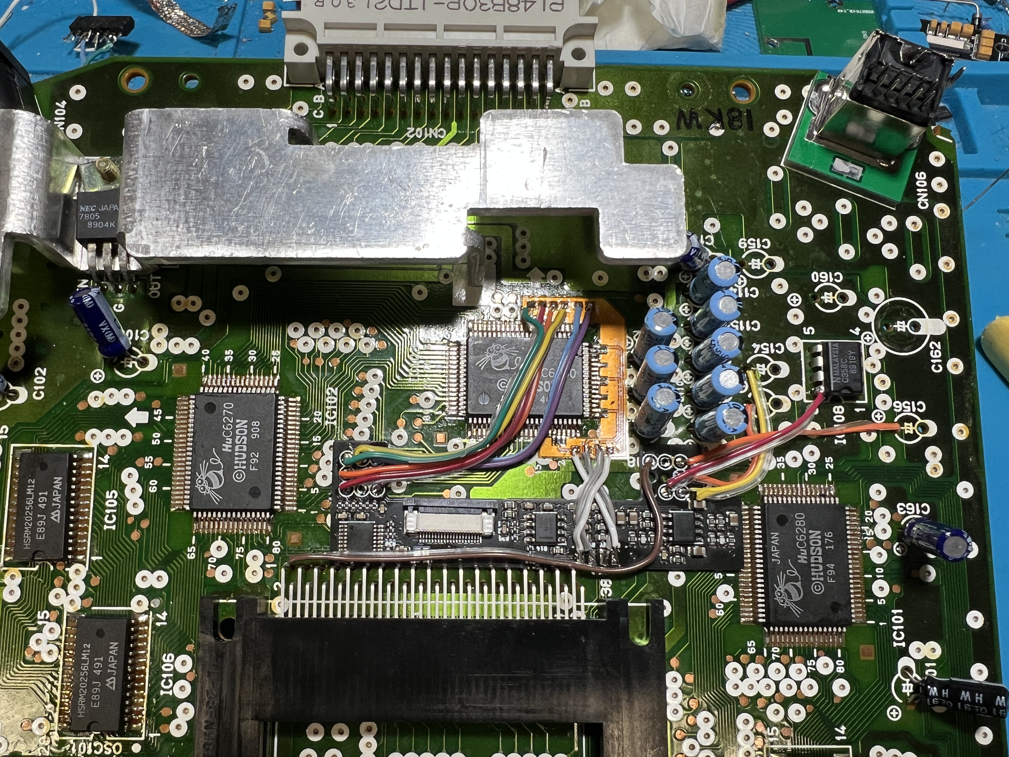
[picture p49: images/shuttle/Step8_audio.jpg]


## Step 10 - Install FFC cable and DIN FFC board

Install the FFC cable to the Turbonanza, Solder the DIN FFC board in place, and connect the FFC to finish the installation.


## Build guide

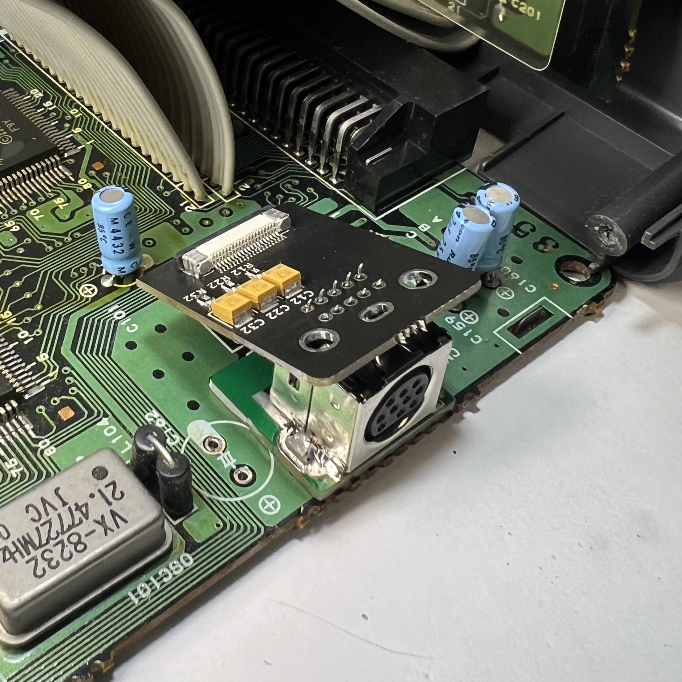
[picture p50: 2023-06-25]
images/RevC_CG_Step5F.jpg

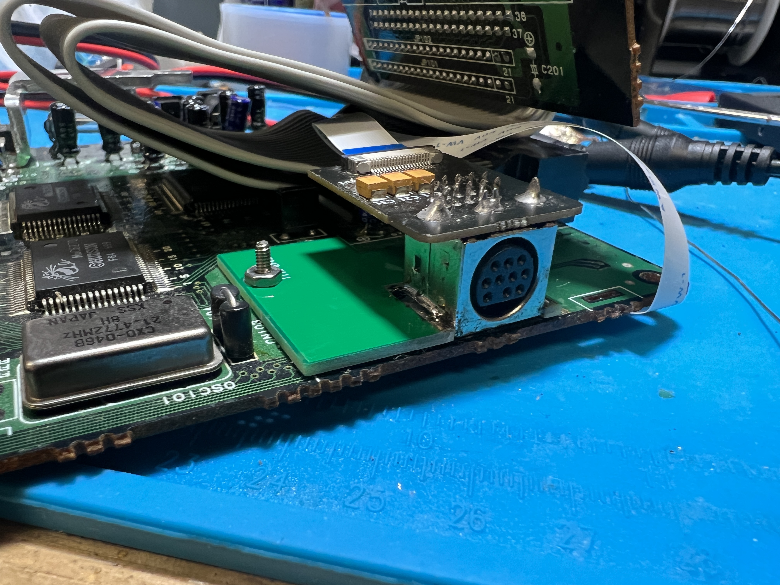
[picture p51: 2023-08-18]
images/PCE_Step5C.jpg

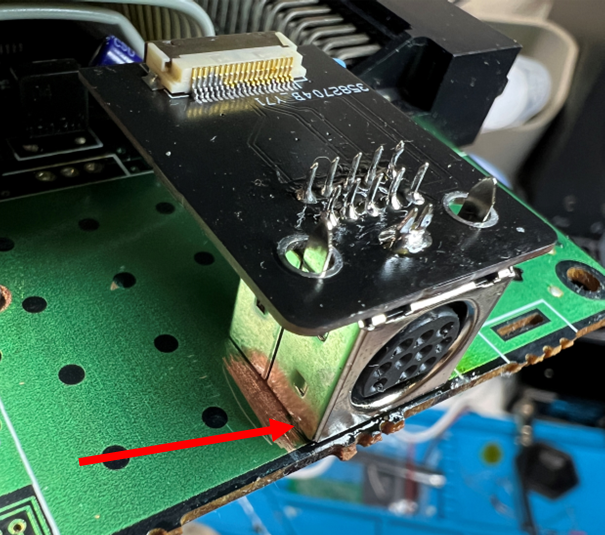
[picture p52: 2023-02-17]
images/Rev C - PCE Step 5 - DIN.png

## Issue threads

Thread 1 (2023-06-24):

Core Grafx DIN mounting board minor issues

bazookaben, 2023-06-24:
I have a Core Grafx and noticed that in Step 5 you didn't mention to scrape away the solder mask on the two sides like for the Super Grafx. The layout of solder points in the AV connector area is identical to Super Grafx so I assume you just forgot to mention that in the Core Grafx section.

Also, there's a capacitor very close by that prevents me from perfectly centering the mounting board. Only off by a few millimeters probably, so no big deal. But thought I'd let you know about that too in case you want to make a slightly smaller mounting for Core Grafx in the future

zaxour, 2023-06-25:
Hi Ben,

Thanks for contacting me. I have updated the readme since I finally have a
CoreGrafx of my own to take pictures with. That large 470uF capacitor next
to the DIN is made unnecessary by the TurboNanza, so it can be removed
safely. Please take a look:

https://github.com/zaxour/TurboNanza#coregrafx

Thanks,
Zack

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

zaxour, 2023-06-26:
Hi Ben,

You're absolutely correct. This is something else I will be adding more
information on as I do the mod on the CG.

Thanks,
Zack

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

zaxour, 2023-06-26:
I use the direct option, which sets the L/R audio channels to 100%, I
believe. I don't touch the CDDA/PCM values. I haven't done an MDFourier
analysis on it yet to figure out what the best presets are.

Thanks,
Zack

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

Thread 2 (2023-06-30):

PC Engine Mounting Board

ridoluk, 2023-06-30:
Will you supply owners of PC Engine with a proper mounting board? The current method of scraping off the solder mask and soldering directly to the PC Engine PCB is not mechanically sound over many cycles.

This resulted in the DIN connectors tearing completely off, taking a fairly sizable chunk of the underlying PCB in the RF area with it on the motherboard. Thankfully, it didn't tear off the RF through hole on the front.

If I had been slightly less lucky, this could've caused considerable damage.

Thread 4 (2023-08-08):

HD Retrovision cables

superbulk, 2023-08-08:
I recently installed the Turbonanza kit in my PC Engine system. I tested both a standard Saturn RCA cable and the HD Retrovision cables. On the RCA is got a picture and sound however on the HD Retrovision cables I got no picture and a buzzing sound and no other audio. I was wondering if these cables are compatible or if there is another mod I need to make to the system. The 10 pin din connector did show up with some damage on the outside shell indicating that it might have be crushed during shipping but since the RCA side works I am not sure what to check next?

zaxour, 2023-08-08:
Could you please email pictures to ***@***.***?

Thanks,
Zack

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

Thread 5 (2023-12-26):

SSDS3 Incompatibility

Peredonov, 2023-12-26:
I tried to hook up an old Terraonion SSDS3 to a Turbonanza'd PC Engine to load CD games from the former while using S-video from the latter, but the SSDS3 cannot start (either displays a white screen or a green screen with garbled graphics and audio noise). The SSDS3 works perfectly on non-Turbonanza consoles (and it has always worked with consoles modded with other RGB mods). The Turbonanza'd console works well otherwise (and is compatible with a Super CD-ROM attachment).

It would be good for someone with both an SSDS3 and a Turbonanza mod to confirm.

zaxour, 2023-12-26:
That’s really strange. I have personally tested an SSDS3 on a bonanza system and it has worked fine. The bonanza doesn’t touch any of the digital bus lines, so I’m not sure what would be causing the issue. I’ll try the ssds with a few systems and see what the results are.

Thanks,
Zack
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

Peredonov, 2023-12-27:
Thanks for checking. The console that has this problem for me is a white PCE, the SSDS3 powers on, green LED turns on, but it seems like the menu system is not able to load.

Please let me know if you have any ideas about anything on the PCE board that could have gotten messed up during the bonanza install that might be interfering with the SSDS3 loading.

zaxour, 2024-01-21:
Sorry for the delay. I just double checked SSDS3 compatibility on my CoreGrafx and it was working fine. You may want to make sure that the SSDS3 is fully seated. Further, you can use the bonanza video output when using SSDS3 to take advantage of svideo.

Zack
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

projectzero, 2024-05-14:
I had the same problem with my recent install on a CoreGrafx - white/green garbled screen and audio noise. Interestingly, the graphics were fine if I used an Everdrive 2.5 and bypassed the flashcard capabilities of the SSDS3 (but still used it's video out). I fixed the issue by removing the bottom shielding around the expansion port pins (did keep the 2 pins that connect near the port) - previously I had left this shielding off as I'm using one of the aftermarket clear shells.

I do have a noticeable audio hum/buzz when using the SSDS3 flashcart capabilities and video out through the Turbonanza (SCART or HDRetrovision cables). I don't *think* it's an SD card issue as the hum is constant and not just during disk access but since I solved the bigger issue (SSDS3 flashcard), I'll troubleshoot the hum later.

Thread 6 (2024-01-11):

Reversed phase in audio ?

karaschen, 2024-01-11:
Hi Zack,
I recently received my newly bought Turbo Everdrive Pro, but forgot to order the EDFX with it.
I bought an EXP output add-on from some DIYer, but it does not have a proper CD audio mixer circuit on it.
I happened to see this TurboNanza on Youtube. It's really a excellent project and I‘m going to order PCB and components to build one myself.
I checked the schematics out of curiosity. I'm not proficient in audio amp circuit, but it seems the audio output phase is reversed from the input.  The audio circuit from an original NEC AV booster does not have a reversed output. Not sure if there is any difference in hearing?
Please let me know if I misunderstand something.

Thanks!
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

zaxour, 2024-01-11:
Hi there,

You are correct, I am using an inverting opamp as opposed to non-inverting used in NEC’s original designs, which does change the phase. However, in the PCE duo, the opamps are inverting, similar to my configuration. Ultimately, it sounds fine and I haven’t heard of anyone else’s experience being negatively impacted as a result of the phase change.

Thanks for bringing that to my attention!

Zack
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

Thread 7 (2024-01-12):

Can't SVIDEO and RGB coexist?

Cyrus331, 2024-01-12:
My PCEINGINE model is TG001. Can't SVIDEO and RGB coexist? Step 4 - Solder S-Video connections. After I operated, SVIDEO could be used, but there was no RGB signal output. Later, I did not remove those resistors and directly connected the SVIDEO terminals to the corresponding solder joints. The result can coexist, that is, both It can output SVIDEO or RGB, but today when I used SVIDEO to output, the picture suddenly became dark, as if there was a lack of brightness, but the colors were still there. I wonder if it was because I did not remove the resistor?

When I tried removing any of the resistors R145, R141 or R134, there was no RGB signal output, so I had to keep these resistors.
The dark picture is SVIDEO, and the bright picture is normal AV picture.
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

Cyrus331, 2024-01-12:
I followed the steps again to remove those resistors, but the SVIDEO picture was still dark.
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

zaxour, 2024-01-13:
Hi,

S-video and RGB can absolutely coexist. Did you build the bonanza yourself?
If so, I would go back and make sure that proper component values were
used. What cables are you using for RGB? The sync signal from the PCE is
fairly low, so some cables might not have enough margin - I would suggest
Sync on Luma if possible.

Also, the FFC is very difficult to hand solder. I would recommend reflowing
if possible.

Zack

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

Cyrus331, 2024-01-14:
Thanks for the reply. Now the problem is solved when I connect the Y signal to R145. If the same effect can be achieved without removing the resistors, why were those resistors disconnected in the original design? It's because The sync signal from the PCE is
Fairly low, so some cables might not have enough margin?

zaxour, 2024-01-14:
I found that the svideo signal was too noisy if I tapped the signals directly, so I reimplemented the whole circuit on my board. How are you connecting your cable? If everything is going through the bonanza output, I don’t see how your TV would be pulling the signals low. The only time I’ve seen that is if using one of those adapters from AliExpress where composite video is not buffered. This causes the composite signal to be loaded down. It doesn’t happen when using a proper output device.

Zack
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

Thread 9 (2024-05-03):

New TurboNanza install black screen and buzzing sound

TruREALigion, 2024-05-03:
I installed on PC Engine but no picture and loud buzzing sound.  Wondering what troubleshooting steps I can try?

It works fine when I plug into my IFU unit.

I used SCART RetroGamingCablesUK and HD retrovision Component cable with Saturn converter

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

zaxour, 2024-05-03:
Hi,

Can you show me how you installed the DIN? I've seen people install it
upside down, just want to make sure that's not the case.

Thanks!

On Thu, May 2, 2024 at 9:36 PM TruREALigion ***@***.***>
wrote:

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

TruREALigion, 2024-05-03:
I didn’t install the DIN actually.  It is just hanging outside.  Does it need to be mounted in for it to work?

zaxour, 2024-05-03:
It doesn’t need to be mounted to the system to work. However, I would like to confirm how you’ve soldered on the small DIN board.
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

TruREALigion, 2024-05-03:
See attached

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

zaxour, 2024-05-03:
The din board is upside down, that would be why you’re not getting an output. Please desolder and flip it over.
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

TruREALigion, 2024-05-03:
That explains everything!

Will update back and close if resolved.

TruREALigion, 2024-05-03:
Fixed.  I had the DIN upside-down.

Closed 2024-05-03.

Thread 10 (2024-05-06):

HuFlex for HuC6260 issue

TruREALigion, 2024-05-06:
Hello

Are pins 41 (+5V) and 42 (Y+) connected or did I accidentally bridge them?

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

zaxour, 2024-05-06:
Hi,

They are connected together by design, as Y+ actually refers to the voltage
supply for the luma section (likely some kind of output buffer/driver).
False alarm!

On Mon, May 6, 2024 at 3:38 PM TruREALigion ***@***.***>
wrote:

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

TruREALigion, 2024-05-06:
Excellent - I thought I was losing my mind scraping my iron over and over!

Closed 2024-05-06.

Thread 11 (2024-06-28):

question about replacing older rgb mod on a pc engine console

matvenu, 2024-06-28:
I want to replace an existing rgb mod on my pc engine with a turbonanza. The mod is Tim Worthington's av-driver.
That specific mod, comes with two 4.7 uF  smd capacitors, to replace c133 and c135 in order to fix a jailbar issue.

Meanwhile, checking the installation instructions of Turbonanza, it isn't a requirement for these two capacitors to be swapped. Since these capacitors are already swapped in my console, do I need to replace them?

zaxour, 2024-06-28:
Hi,

I would leave the 4.7u capacitors, as those are for the jailbar fix. I don’t cover that since it’s something that’s covered by a typical recap procedure.
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

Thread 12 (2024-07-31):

Din board Pinout

OmenBoy, 2024-07-31:
Is there a pinout for the where the din connector connects to its board? I think I may have heated up the din connector too much and melted the inside, because the connection is so tight that the same pin keeps breaking on my cables. I don't want to buy more cables so I would like to just solder an AV or S-Video cable directly to where the din connects. I also have an issue where I don't get audio or video, just a buzzing sound. I would like to test to see if the din connector is the issue. Thank you.

zaxour, 2024-07-31:
Hi,

It’s possible that you put the din connector on upside down, if it’s a PCE/CG. If it’s the long narrow connector, make sure you can see the text “this side top.”

If you’d like to get a replacement connector, digikey (and others) have them:

https://www.digikey.com/en/products/detail/kycon-inc/KMDGX-10S-BS/10247002

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

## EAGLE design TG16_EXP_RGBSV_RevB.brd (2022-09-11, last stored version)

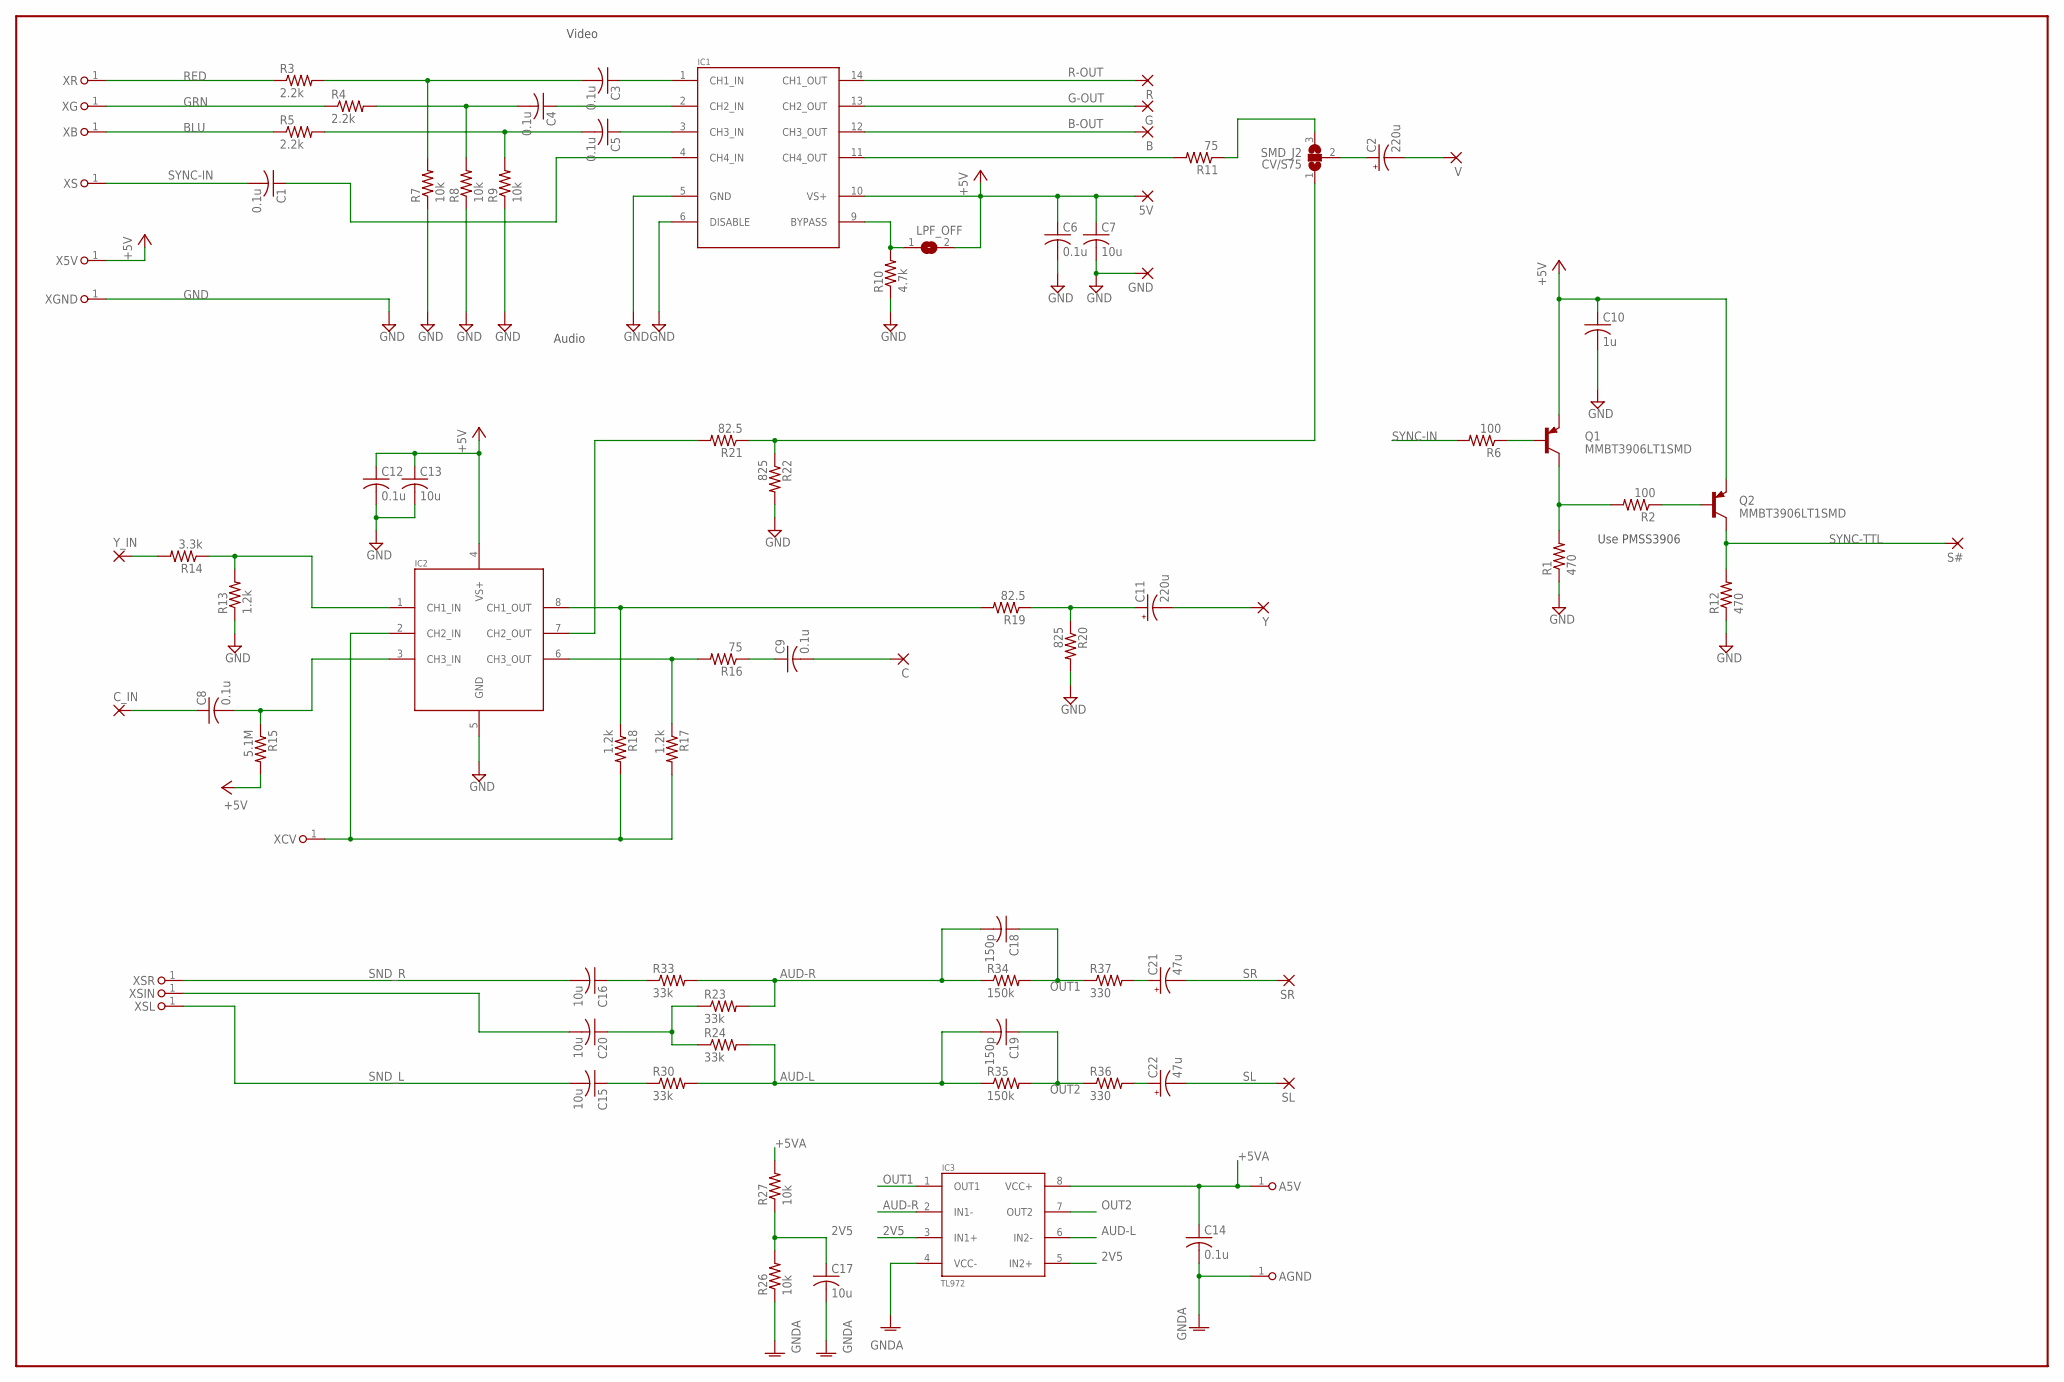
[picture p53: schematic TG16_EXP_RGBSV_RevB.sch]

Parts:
5V: SMD2; SMD1,27-2,54
A5V: PINHD-1X1; 1X01
AGND: PINHD-1X1; 1X01
B: SMD2; SMD1,27-2,54
C: SMD2; SMD1,27-2,54
C1, C3, C4, C5, C6, C8, C9, C12, C14: 0.1u; C0603
C2, C11: 220u; CT3528
C7, C13, C17: 10u; C1206
C10: 1u; C0603
C15, C16, C20: 10u; C0805
C18, C19: 150p; C0603
C21, C22: 47u; CT3528
CV/S75: SMD_J2; SJ_2
C_IN: SMD2; SMD1,27-2,54
G: SMD2; SMD1,27-2,54
GND: SMD2; SMD1,27-2,54
IC1: THS7374TSSOP14_LONG; TSSOP14LONG
IC2: THS7314; SOIC8
IC3: TL972; SOIC8
LPF_OFF: SMD_J; SJ
Q1, Q2: MMBT3906LT1SMD; SOT23-BEC
R: SMD2; SMD1,27-2,54
R1, R12: 470; R0603
R2, R6: 100; R0603
R3, R4, R5: 2.2k; R0603
R7, R8, R9, R26, R27: 10k; R0603
R10: 4.7k; R0603
R11, R16: 75; R0603
R13, R17, R18: 1.2k; R0603
R14: 3.3k; R0603
R15: 5.1M; R0603
R19, R21: 82.5; R0603
R20, R22: 825; R0603
R23, R24, R30, R33: 33k; R0603
R34, R35: 150k; R0603
R36, R37: 330; R0603
S#: SMD2; SMD1,27-2,54
SL: SMD2; SMD1,27-2,54
SR: SMD2; SMD1,27-2,54
V: SMD2; SMD1,27-2,54
X5V: PINHD-1X1; 1X01
XB: PINHD-1X1; 1X01
XCV: PINHD-1X1; 1X01
XG: PINHD-1X1; 1X01
XGND: PINHD-1X1; 1X01
XR: PINHD-1X1; 1X01
XS: PINHD-1X1; 1X01
XSIN: PINHD-1X1; 1X01
XSL: PINHD-1X1; 1X01
XSR: PINHD-1X1; 1X01
Y: SMD2; SMD1,27-2,54
Y_IN: SMD2; SMD1,27-2,54

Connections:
2V5: C17.1, IC3.3 (IN1+), IC3.5 (IN2+), R26.2, R27.1
+5V: 5V.1, C6.1, C7.1, C10.1, C12.1, C13.1, IC1.10 (VS+), IC2.4 (VS+), LPF_OFF.2, Q1.E, Q2.E, R15.2, X5V.1
+5VA: A5V.1, C14.1, IC3.8 (VCC+), R27.2
AUD-L: C19.2, IC3.6 (IN2-), R24.2, R30.2, R35.1
AUD-R: C18.2, IC3.2 (IN1-), R23.2, R33.2, R34.1
B-OUT: B.1, IC1.12 (CH3_OUT)
BLU: R5.1, XB.1
G-OUT: G.1, IC1.13 (CH2_OUT)
GND: C6.2, C7.2, C10.2, C12.2, C13.2, GND.1, IC1.5 (GND), IC1.6 (DISABLE), IC2.5 (GND), R1.1, R7.1, R8.1, R9.1, R10.1, R12.1, R13.1, R20.2, R22.2, XGND.1
GNDA: AGND.1, C14.2, C17.2, IC3.4 (VCC-), R26.1
GRN: R4.1, XG.1
unnamed: Q1.B, R6.1
unnamed: C3.1, IC1.1 (CH1_IN)
unnamed: C3.2, R3.2, R7.2
unnamed: C4.1, IC1.2 (CH2_IN)
unnamed: C4.2, R4.2, R8.2
unnamed: C5.1, IC1.3 (CH3_IN)
unnamed: C1.1, IC1.4 (CH4_IN)
unnamed: C5.2, R5.2, R9.2
unnamed: IC1.9 (BYPASS), LPF_OFF.1, R10.2
unnamed: Q1.C, R1.2, R2.2
unnamed: IC1.11 (CH4_OUT), R11.2
unnamed: Q2.B, R2.1
unnamed: C2.+, CV/S75.2
unnamed: C2.-, V.1
unnamed: R14.2, Y_IN.1
unnamed: IC2.1 (CH1_IN), R13.2, R14.1
unnamed: C8.1, C_IN.1
unnamed: C8.2, IC2.3 (CH3_IN), R15.1
unnamed: IC2.8 (CH1_OUT), R18.1, R19.2
unnamed: IC2.6 (CH3_OUT), R16.2, R17.1
unnamed: C9.1, R16.1
unnamed: C.1, C9.2
unnamed: IC2.2 (CH2_IN), R17.2, R18.2, XCV.1
unnamed: C11.+, R19.1, R20.1
unnamed: C11.-, Y.1
unnamed: IC2.7 (CH2_OUT), R21.2
unnamed: CV/S75.3, R11.1
unnamed: CV/S75.1, R21.1, R22.1
unnamed: C16.1, R33.1
unnamed: C20.2, XSIN.1
unnamed: C20.1, R23.1, R24.1
unnamed: C15.1, R30.1
unnamed: C22.+, R36.2
unnamed: C21.+, R37.2
OUT1: C18.1, IC3.1 (OUT1), R34.2, R37.1
OUT2: C19.1, IC3.7 (OUT2), R35.2, R36.1
R-OUT: IC1.14 (CH1_OUT), R.1
RED: R3.1, XR.1
SL: C22.-, SL.1
SND_L: C15.2, XSL.1
SND_R: C16.2, XSR.1
SR: C21.-, SR.1
SYNC-IN: C1.2, R6.2, XS.1
SYNC-TTL: Q2.C, R12.2, S#.1

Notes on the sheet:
Audio
Video
Use PMSS3906

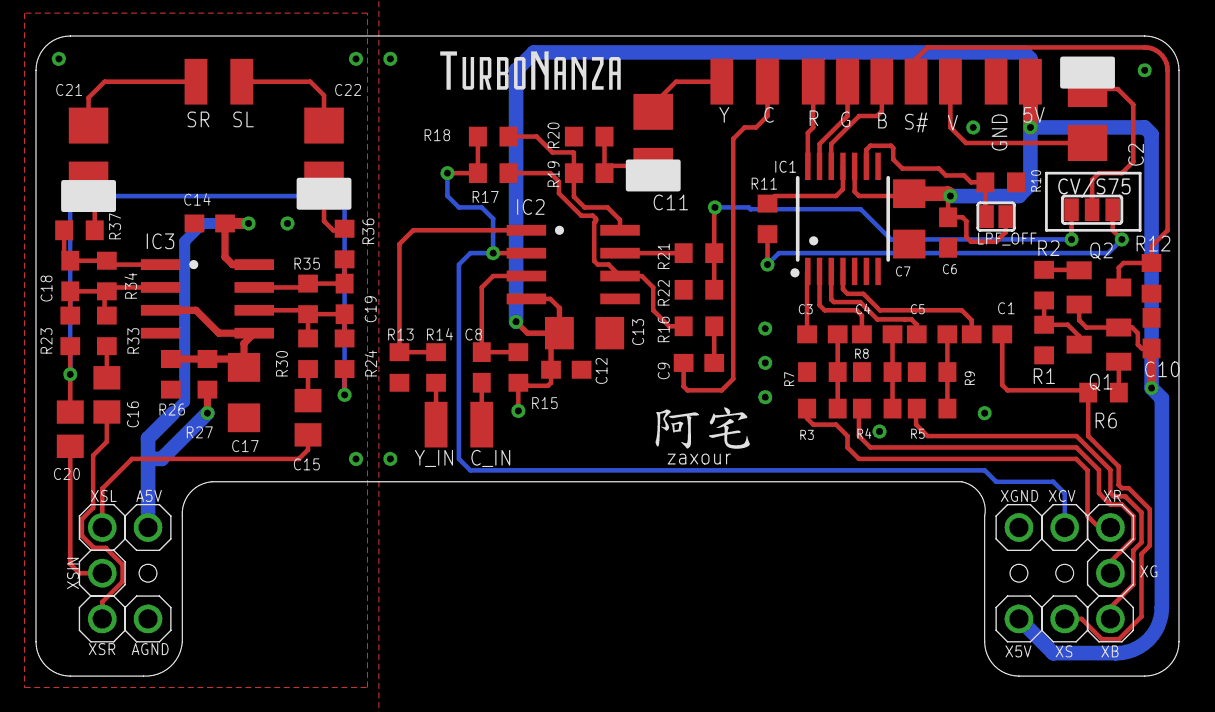
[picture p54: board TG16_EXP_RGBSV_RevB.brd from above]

Board: 2 copper layers, 63.5 x 35.6 mm, 86 parts (0 on the bottom side), 55 nets.

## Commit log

2022-09-25 Add files via upload
    Replaced Eagle version with revised KiCad version
2023-08-15 Add files via upload
    PC Engine mounting board added
2024-09-21 Update readme.md
    Forgot about resistor removal; not critical, but suggested to do so.
2025-09-28 Update README.md
    Updated DIN mounting instructions for PCE/CG
